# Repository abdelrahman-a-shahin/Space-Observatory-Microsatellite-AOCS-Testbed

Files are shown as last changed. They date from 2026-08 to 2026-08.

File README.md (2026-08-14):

# Space-Observatory-Microsatellite-AOCS-Testbed
My graduation project at Aerospace Engineering, New Mansoura University, in Egypt. Going through the design, simulation, and implementation process of a ground model customized cube-sat for space observation. And to validate the CubeSat's attitude, navigation & control an AOCS testbed was made to simulate Earth's geomagnetic field and the frictionless motion of the satellite in space.



https://github.com/user-attachments/assets/0b6dd6ed-a356-4bd0-b43c-fc6ba49cf2e2

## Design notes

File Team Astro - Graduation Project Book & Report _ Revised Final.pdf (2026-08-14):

New Mansoura University

Faculty of Engineering

Aeronautical & Aerospace Engineering Program

## Graduation Project

## Space Observatory Micro-Satellite & AOCS Testbed

## Students’ names:

Name | ID Number
Abdelrahman Ahmed Abdelhadi Shahin | 221101236
Abdelrahman Elsaied Nassim Yakoub | 221101237
Ezzeldeen Mohammed Amin AboElkasim | 221101241
Abdelrahman Ehab Awad Ramdan | 221101238
Dana Elsayed Abdelhadi Elansari | 221101234
Mostafa Hassan Anwar Abdallah | 221101257
Ali Abdelhakim Ibrahim Sakr | 221101242
Amr Khaled Youssef Balat | 221101245

## Supervised by:

Assoc. Prof. Sara Ahmed El-Bahloul | Assoc. Prof. Osama El-Shazly Habib

Dr. Ahmed Salah Saad

Spring 2026

## ACKNOWLEDGEMENTS

First and foremost, we would like to express our deepest gratitude and sincere

appreciation to Prof. Wael Seddik, Dean of the Faculty of Engineering, for his continuous

support, encouragement, and efforts in providing a motivating academic environment

that enables students to develop their engineering knowledge and practical skills.

We would also like to extend our sincere thanks to Assoc. Prof. Sara Elbahloul, Program

Directors, for her valuable guidance, continuous follow-up, and dedication to the

development of the program and its students.

Our heartfelt appreciation goes to our project supervisors, Assoc. Prof. Sara Ahmed El-

Bahloul, Assoc. Prof. Osama El-Shazly Habib, and Dr. Ahmed Salah Saad, for their

invaluable supervision, constructive feedback, technical guidance, and continuous

support throughout all stages of this graduation project. Their knowledge, experience,

and encouragement were essential to the successful completion of this work.

Special thanks are also extended to our project mentor, Eng. Ismail Ezz El-Din, for his

valuable technical advice, practical support, and continuous assistance during the design,

implementation, and testing phases of the project.

Finally, we would like to express our deepest gratitude to our families for their endless

love, patience, encouragement, and support throughout our academic journey. Their

belief in us has been a constant source of motivation and strength, and this achievement

would not have been possible without them.

## ABSTRACT

The Egyptian Gamma Observation Satellite (EGOS-1) is a space observatory micro-

satellite designed and developed by Team Astro at New Mansoura University as part of

the 2025–2026 graduation project for the Aeronautical and Aerospace Engineering

Program. The project encompasses two parallel and complementary deliverables: the

conceptual design and systems-level engineering of a gamma-ray observation micro-

satellite, and the design, fabrication, and experimental validation of a ground-based

Attitude and Orientation Control System (AOCS) evaluation testbed simulating the LEO

magnetic and rotational environment.

EGOS-1 is a 20 × 20 × 20 cm micro-satellite designed for a sun-synchronous circular orbit

at 550 km altitude. Its primary payload is a NaI(Tl) scintillation detector coupled to a

BPW34 photodiode array for gamma-ray flux detection. Structural integrity was

confirmed through static, thermal, and modal finite-element analyses, yielding a factor of

safety of 7 under 10G launch loading, thermal compliance at a peak frame temperature of

411.51 K, and adequate dynamic stiffness across six vibration modes. Attitude control is

achieved via a reaction wheel, dual custom magnetorquers, and a PSO-tuned PD controller

executed on an ESP32 microcontroller, with real-time telemetry accessible through a Wi-

Fi-hosted dashboard.

The AOCS testbed comprises a three-axis rectangular Helmholtz cage and a spherical

aerostatic air bearing. The Helmholtz cage generates a uniform magnetic field in the LEO

operational range (0.3–0.6 Gauss at 5 A), confirmed by Wolfram-based magnetic

simulation and real-world testing. The air bearing, 3D-printed in PLA with 13 × 1.0 mm

orifices at 6 bar supply pressure, was validated by independent SOLIDWORKS Flow Simulation and ANSYS Fluent 2025 R1 analyses, with both tools agreeing on a lifting force

of 49.85 N to within 0.01%. Both the satellite Earth prototype and the testbed were

successfully fabricated and demonstrated at New Mansoura University.

## TABLE OF CONTENTS

## LIST OF FIGURES

Figure 5 EGOS-1 ground track illustrating the satellite passing over Egypt for the downlink

Figure 6 Eclipse simulation for EGOS-1 in orbit using SatCatalog. The maximum eclipse

Figure 7 The payload sensor consisting of a NaI(Tl) crystal incapsulated in an aluminum case (transparent in the figure) and connected to the BPW34 light sensors at the bottom.

Figure 10 Exploded view of EGOS-1 illustrating all sub-systems and components in a nest

Figure 11 Mesh quality plot and boundary conditions showing the red arrow as the 10G external load and the green arrows as the fixture on the bottom plate in the left image.

Figure 12 Boundary conditions of the thermal simulation of EGOS-1 showing the arrows as

Figure 13 Mesh quality plot for the modal analysis (the left image), and the fixed support of

Figure 18 Results summary of the static, thermal and modal analysis of EGOS-1 microsatellite.

Figure 19 3D CAD model performed on SOLIDWORKS of the helmholtz cage structure &

Figure 20 Spherical air bearing 3D CAD model on SOLIDWWORKS, showing the isometric view and the sectional front view to illustrate the air chamber and the central orifice. .51

Figure 21 Full system 3D CAD model showing 2 various views, and the top view to illustrate the gripping mechanism on the microsatellite, showing 2 diagonal tight grips and 2 loose
grips | 51

Figure 22 The input parameters for the Helmholtz cage simulation to solve for the magnetic
flux density and the homogenious distance | 52

Figure 23 SOLIDWORKS Flow Simulation boundary conditions for the spherical air bearing: inlet total pressure 600,000 Pa (left) and environment pressure outlet 101,325 Pa (right).
Simulation goals are listed in the centre panel | 53

Figure 24 ANSYS Fluent 2025 R1 setup for the spherical air bearing CFD simulation: bowl geometry with pressure inlet at 600,000 Pa gauge (normal to boundary), and velocity
streamline initialisation showing the eight orifice inlet jets | 54

Figure 25 Wolfram Demonstration magnetic simulation for the XZ plane (2a = 0.75 m, N = 5, I = 5 A): B_z vs z (left) and B_z vs y (right) profiles, confirming B_z(0,0,0) = 0.542915
Gauss and a broad uniform-field plateau | 55

Figure 26 SolidWorks Flow Simulation results at iteration 85: velocity flow trajectories (left, scale 0–365 m/s) showing symmetric air film formation between the orifice jets and the sphere surface. The results table (right) shows GG Force Y = 49.845 N (averaged)......56

Figure 27 The final purchased components (right image) & The final schematic (left image).
| 61

Figure 28 Plate assembly of the frame using the tab-and-slot feature to install the mounting
strips that will hold the plates together, also showing the mounting shelf | 62

Figure 29 The CNC laser cutting process of the structural frame plates (left image), the plates and mounting strips before assembly (middle image), the plates during assembly using
4mm button head bolts with nuts (right image.) | 62
Figure 30 Telemetry dashboard for EGOS-1 microsatellite | 64
Figure 31 The control algorithim for the microsatellite's software | 65

Figure 32 The U-channel aluminum profile (left image), The 4mm2 stranded insulated wire
(middle image), The zip ties used as fasteners (right image) | 67

Figure 33 Final modelling of the assembly on SOLIDWORKS (left image), The 3D printing process of the parts (middle images), Final implemented assembly with stand (right
image) | 67
Figure 34 Testbed operation diagram | 69

Figure 35 Full testbed + specimen project operating in a lab at New Mansoura University.69

## LIST OF TABLES

Table 4 Helmholtz cage magnetic simulation results: central field and uniform region for each

Table 5 SolidWorks Flow Simulation results for the spherical air bearing (6 bar inlet, 13 × 1.0

Table 6 ANSYS Fluent 2025 R1 CFD results for the spherical air bearing. Both tools agree on

CHAPTER 1:INTRODUCTION

# 1. Introduction

Space science has emerged as one of the most transformative fields driving scientific

progress and technological development in the modern era. Over the past several

decades, humanity’s ability to deploy instruments and platforms beyond the confines of

the Earth’s atmosphere has fundamentally altered our understanding of the universe and

has enabled a wide spectrum of applications that directly underpin daily life on Earth.

From global telecommunications networks to precise navigation systems, from climate

monitoring to disaster response, space-based infrastructure has become an essential

element of the modern world’s operational backbone.

The development and launch of artificial satellites represent arguably the single most

consequential achievement of the space age. Since the launch of Sputnik 1 in 1957,

satellites have evolved from simple radio beacons into sophisticated engineering

platforms carrying instruments of extraordinary complexity and sensitivity. Today,

constellations of satellites provide continuous coverage of the Earth’s surface, enable

real-time global communications, deliver precise positioning data to billions of users, and

support scientific investigations ranging from Earth observation to deep-space

astrophysics. The cumulative economic, social, and scientific impact of satellite

technology is difficult to overstate BeiDou provide sub-meter positioning accuracy [14].

Artificial satellites serve a remarkable diversity of functions. In the domain of

telecommunications, geostationary satellites relay voice, data, and broadcast signals

across continents and oceans, forming the invisible backbone of the global internet and

telephone infrastructure. In navigation, constellations such as the Global Positioning

System (GPS), GLONASS, Galileo, and BeiDou provide sub-meter positioning accuracy

that supports aviation, maritime navigation, precision agriculture, autonomous vehicles,

and emergency services. In meteorology, polar-orbiting and geostationary weather

satellites continuously monitor atmospheric conditions, enabling forecasts that save lives

and protect economies. In Earth observation, multispectral and hyperspectral sensors

map land use, monitor deforestation, track sea-ice extent, and assess agricultural yields,

providing decision-makers with data critical for environmental stewardship and

sustainable development [17].

CHAPTER 1:INTRODUCTION

Beyond these utilitarian applications, satellites have opened an entirely new window on

the universe. Space-based observatories, freed from the blurring and absorptive effects

of the Earth’s atmosphere, observe the cosmos across the full electromagnetic spectrum,

from gamma rays and X-rays through ultraviolet, visible, and infrared wavelengths to

radio frequencies. Missions such as the Hubble Space Telescope, the Chandra X-ray

Observatory, the Fermi Gamma-ray Space Telescope, and the James Webb Space

Telescope have revolutionized astrophysics, cosmology, and planetary science, delivering

data that challenge and refine our theoretical understanding of the universe’s origin,

structure, and evolution [20].

In recent years, the satellite industry has undergone a profound democratization driven

by the rise of micro-satellites and CubeSats. Traditional large satellites, with masses

measured in hundreds or thousands of kilograms and development costs in the hundreds

of millions of dollars, have historically been accessible only to major space agencies and

large commercial entities. Micro-satellites, defined as spacecraft with a mass between

approximately 10 and 100 kilograms, and even smaller CubeSats based on standardized

10 × 10 × 10 cm unit (1U) form factors, have dramatically lowered the barriers to space

access. Standardized launch vehicle interfaces, off-the-shelf electronic components, and

streamlined development methodologies have enabled universities, research

institutions, and technology start-ups to design, build, and launch space-qualified

platforms on timescales of one to three years and at costs orders of magnitude lower than

traditional satellite programs [15].

This democratization has had a catalytic effect on both scientific research and

engineering education. Universities around the world now routinely develop and operate

small satellites as educational platforms, training the next generation of aerospace

engineers in systems integration, orbital mechanics, attitude control, communications,

and mission operations. At the same time, micro-satellites are increasingly used for

genuine scientific investigations, commercial Earth observation, technology

demonstration, and in-orbit validation of new components and systems. The

miniaturization of sensors, processors, and power systems has reached a point where a

spacecraft the size of a shoebox can carry scientifically meaningful payloads and generate

commercially valuable data.

CHAPTER 1:INTRODUCTION

Within the constellation of satellite subsystems, the Attitude and Orientation Control

System (AOCS), sometimes referred to as the Attitude Determination and Control System

(ADCS), occupies a position of particular criticality. The AOCS is responsible for sensing

the satellite’s current orientation in space, computing the required corrective maneuvers,

and commanding actuators to reorient the spacecraft so that its instruments, antennas,

and solar panels are pointed toward their intended targets with the required accuracy.

For a space observatory, this pointing requirement is especially demanding: scientific

instruments must be held precisely on a celestial target long enough to collect statistically

meaningful data, and the pointing knowledge must be accurate enough to assign the

collected data to the correct position on the sky.

A typical AOCS integrates several types of sensors to determine attitude. Magnetometers

measure the local geomagnetic field vector, which can be compared to a model of the

Earth’s field to infer orientation. Gyroscopes, either mechanical or micro-

electromechanical (MEMS), measure angular rates and provide high-bandwidth attitude

rate information. Sun sensors detect the direction of the Sun relative to the spacecraft

body frame. Star trackers, the most accurate of all attitude sensors, identify patterns of

stars in their field of view and compare them to an onboard star catalog to determine

inertial pointing with arc-second precision. On the actuator side, reaction wheels provide

fine torque control about all three axes by exchanging angular momentum between the

wheel and the spacecraft. Magnetorquers generate magnetic dipole moments that

interact with the Earth’s field to produce control torques, and are particularly useful for

detumbling after launch and for desaturating reaction wheels [18].

The complexity of the AOCS, and the consequences of its failure for mission success, make

thorough ground testing essential before a satellite is committed to orbit. Once in space,

the satellite cannot be physically accessed for repair, and the cost of a failed mission is

not merely the financial investment but the scientific opportunity that is irretrievably

lost. Ground-based AOCS testbeds allow engineers to exercise sensors, actuators, and

control algorithms in a controlled laboratory environment that simulates the key

characteristics of the space environment: a frictionless rotational interface that mimics

microgravity, and a controlled magnetic field environment that replicates the

geomagnetic conditions the satellite will experience in orbit.

CHAPTER 1:INTRODUCTION

Egypt stands at a pivotal juncture in its development of national space capabilities. The

Egyptian Space Agency (EgSA), established in 2018, has articulated a national space

strategy that includes the development of indigenous satellite design and manufacturing

capabilities. In this context, academic programs in aerospace engineering at Egyptian

universities play a vital role in building the human capital that will realize these national

aspirations. Projects that challenge students to design, analyze, and fabricate real space-

qualified hardware contribute directly to the development of a domestic engineering

talent pool capable of supporting Egypt’s long-term space ambitions.

The Space Observatory Micro-Satellite and AOCS Evaluation Testbed project, designated

EGOS-1, is designed in precisely this spirit. The project pursues two complementary

objectives. The first is the conceptual design and analysis of a micro-satellite platform

optimized for gamma-ray observation from Low Earth Orbit, with a scientific mission

focused on the detection and characterization of gamma-ray flux from deep-space

sources. The second is the design, analysis, and fabrication of a laboratory-based AOCS

testbed capable of simulating the magnetic and rotational environment of LEO, enabling

the rigorous validation of AOCS sensors, actuators, and control algorithms prior to any

future launch campaign [21].

Gamma-ray astronomy represents one of the most scientifically rich and technically

challenging domains of space-based observation. Gamma rays are the highest-energy

photons in the electromagnetic spectrum, with energies typically exceeding 100 keV and

often reaching into the GeV and TeV ranges. They are produced by the most energetic

processes in the universe: the accretion of matter onto black holes and neutron stars, the

annihilation of matter and antimatter, cosmic-ray interactions with interstellar medium,

and the violent explosions of massive stars known as gamma-ray bursts. Because gamma

rays are entirely absorbed by the Earth’s atmosphere, they can only be detected by

instruments deployed above the atmosphere, making space-based observatories an

absolute requirement for gamma-ray astronomy.

The EGOS-1 payload employs a sodium iodide thallium-doped scintillation detector, a

technology with a long and proven heritage in space-based gamma-ray detection. When

a gamma-ray photon interacts with the NaI(Tl) crystal, it deposits its energy through a

cascade of photoelectric, Compton scattering, and pair-production interactions,

CHAPTER 1:INTRODUCTION

ultimately producing a burst of visible-wavelength scintillation light. This light is

detected by an array of BPW34 high-sensitivity photodiodes mounted on the crystal’s

lower surface, whose output is amplified and digitized for onboard storage and

subsequent downlink to the ground station.

The project’s dual-component structure—satellite design and AOCS testbed development

conducted in parallel and validated against a common set of mission requirements—

reflects a systems engineering philosophy that is well established in the professional

aerospace community. By developing the testbed in close coordination with the satellite

design, the team ensures that the testbed’s simulation capabilities are directly matched

to the operational envelope of the AOCS that will fly on EGOS-1. Conversely, the testbed

provides a concrete engineering product of immediate value for academic research,

independent of whether and when the satellite itself is eventually launched.

The remainder of this report is organized as follows. Section 2 defines the problem

statement that motivates the project. Section 3 states the project objectives. Section 4

reviews the relevant literature on microsatellite design, gamma-ray payload technology,

and AOCS testbed approaches. Section 5 describes the engineering methodology adopted.

Section 6 presents the technical approach, including design parameters, CAD models,

simulation setups, and results for both the microsatellite and the AOCS testbed. Section 7

describes the deliverables and implementation plan. Section 8 identifies potential

stakeholders. Sections 9 and 10 provide the project conclusion and future work,

respectively.

### 1.1 Space Observatory Microsatellite

A space observatory micro-satellite is a compact, mass-constrained spacecraft

specifically designed to observe and study astronomical objects and physical phenomena

from a vantage point above the Earth’s atmosphere. The absence of atmospheric

absorption and distortion that afflicts ground-based observatories makes space-based

platforms uniquely capable of detecting radiation across the full electromagnetic

spectrum, including the gamma-ray, X-ray, and ultraviolet bands that are completely or

partially blocked by the atmosphere at sea level.

CHAPTER 1:INTRODUCTION

Micro-satellites in this category typically have masses in the range of 10 to 100 kilograms,

and their dimensions are constrained to fit within standardized launch vehicle

dispensers. Despite these mass and volume constraints, modern micro-satellites can

accommodate sophisticated scientific instruments, thanks to the continued

miniaturization of electronics, detectors, and mechanical structures. Advanced system-

on-chip processors provide the computational power needed for onboard data

processing and compression. Low-power, high-sensitivity detectors enable meaningful

science within tight power budgets. Compact attitude control actuators, including

reaction wheels the size of a hockey puck, provide the pointing stability needed for

scientific observation.

The EGOS-1 micro-satellite is designed to detect gamma-ray flux from astrophysical

sources, contributing to the growing body of data from space-based gamma-ray

observatories. Its orbit, subsystem architecture, structural design, and payload

configuration are described in detail in Section 6 of this report. The satellite is designed

with a mission lifetime of one to three years, depending on orbital decay and subsystem

reliability, and is intended to serve as a demonstration platform for Egyptian space

engineering capabilities as well as a scientific instrument contributing to international

gamma-ray observation programs.

### 1.2 AOCS Testbed

The Attitude and Orientation Control System Testbed is a ground-based experimental

platform engineered to simulate and evaluate the performance of a satellite’s attitude

control system in a controlled laboratory environment before the satellite is committed

to space. In the context of the EGOS-1 mission, the AOCS must maintain precise pointing

of the gamma-ray detector toward its intended observation targets, and it must do so

reliably throughout the satellite’s operational lifetime in the presence of environmental

disturbances including aerodynamic drag, solar radiation pressure, gravity gradient

torques, and geomagnetic perturbations.

The testbed enables the experimental validation of attitude sensors, actuators, and

control algorithms by replicating two key aspects of the space environment. The

Helmholtz cage, a system of three mutually orthogonal square coil pairs, generates a

uniform and programmable magnetic field within the cage’s central volume that

CHAPTER 1:INTRODUCTION

replicates the Earth’s geomagnetic field as experienced by a satellite in LEO. This allows

magnetometers and magnetorquers to be tested and calibrated under realistic field

conditions. The spherical air bearing provides a near-frictionless rotational interface on

which a satellite mock-up can rotate freely about all three axes, simulating the near-zero-

friction rotational environment of orbital free-fall.

Together, these two testbed components create a laboratory environment in which the

full AOCS control loop—sensor measurement, state estimation, control law computation,

and actuator command—can be exercised and validated before the satellite encounters

the real space environment. The ability to detect and correct design errors at this stage,

rather than after launch, is enormously cost-effective and is standard practice in

professional satellite engineering programs worldwide.

CHAPTER 2: PROBLEM STATEMENT

# 2. Problem Statement

The exploration of space and the systematic observation of astronomical phenomena

demand satellite systems of high precision, reliability, and operational robustness.

Traditional large satellites, while capable of delivering exceptional scientific data, involve

development costs measured in hundreds of millions of dollars and launch costs that are

beyond the reach of universities and most national space agencies, particularly in the

developing world. These financial barriers severely limit participation in space science

and the development of indigenous satellite engineering expertise.

Micro-satellites represent a compelling cost-effective alternative that has the potential to

democratize access to space-based observation. However, despite their lower cost, the

technical challenges associated with micro-satellite development are not proportionally

reduced. The accuracy and stability of satellite attitude control remain critical for mission

success regardless of satellite scale, and the engineering difficulty of achieving precise,

robust attitude control in a compact, power-constrained platform is substantial. Any

systematic error or instability in the AOCS will result in degraded pointing accuracy,

compromised data quality, and potentially mission failure.

In-orbit testing and debugging of AOCS failures is, in practice, extremely limited. Once a

satellite is deployed, direct physical access is impossible, and the only means of

diagnosing and correcting AOCS anomalies are telemetry analysis and software patch

upload over the communication link. This underscores the critical importance of

comprehensive ground testing before launch. However, the facilities needed for AOCS

ground testing—Helmholtz cages, air bearing platforms, vibration tables, thermal-

vacuum chambers—are expensive to procure and operate, and are typically found only

at major space agencies and large aerospace companies.

This project addresses a specific gap: the absence, within Egyptian academic institutions,

of a dedicated ground-based AOCS evaluation testbed that allows researchers and

engineering students to design, test, and validate satellite attitude control systems under

realistic simulated space conditions. By designing and fabricating such a testbed locally,

using a combination of commercial off-the-shelf components and custom-designed

mechanical parts, the project demonstrates that it is possible to create a functional,

CHAPTER 2: PROBLEM STATEMENT

scientifically meaningful AOCS test facility at a cost accessible to university programs.

Simultaneously, by designing the EGOS-1 microsatellite as the reference system for the

testbed, the project produces a complete systems engineering case study that links

mission requirements to testbed specifications.

CHAPTER 3: OBJECTIVES

# 3.Objectives

The main objectives of this project are:

To localize the fabrication of a high-efficiency, cost-effective Attitude and

Orientation Control System (AOCS) testing apparatus, enabling reliable experimental

validation of spacecraft attitude control subsystems. This involves the end-to-end design,

manufacturing, and assembly of the testing platform using locally sourced components

and domestic engineering expertise, thereby reducing dependence on imported systems.

The apparatus will be capable of simulating realistic rotational dynamics and disturbance

torques, providing a controlled environment in which AOCS algorithms and hardware

configurations can be rigorously evaluated, calibrated, and refined prior to integration

into the flight model.

To design a compact space observatory micro-satellite platform incorporating

advanced sensors and payloads, with AI-enhanced data acquisition and interpretation

for improved astronomical observation. The satellite platform will be engineered to meet

the stringent mass, volume, and power constraints characteristic of the micro-satellite

class, while accommodating a scientifically capable optical and sensing payload suite. The

integration of artificial intelligence and machine learning techniques into the onboard

data pipeline will enable autonomous feature extraction, anomaly detection, and

prioritized downlink of high-value observational data, significantly enhancing the

platform's scientific return within its operational constraints.

To provide affordable and accessible testing capabilities for universities and

research institutions, supporting hands-on experimentation and academic training in

satellite systems engineering. A central consideration in the design philosophy of the

testing apparatus is its replicability and ease of use within academic settings that may

have limited infrastructure or funding. By documenting the development process

thoroughly and optimizing the system for low-cost production, this project aims to

democratize access to spacecraft subsystem testing, enabling the next generation of

aerospace engineers to gain practical, laboratory-grade experience with real-world

satellite technologies.

CHAPTER 3: OBJECTIVES

To contribute to Egypt's advancement in space science and technology by designing

and prototyping the nation's first space observatory micro-satellite, fostering local

expertise and capability in aerospace engineering and scientific research. Beyond the

immediate technical deliverables, this project is positioned as a foundational milestone

in building a sustainable domestic space industry. Through the involvement of local

engineers, academic institutions, and research bodies, the project seeks to cultivate a

multidisciplinary knowledge base, stimulate innovation, and establish the technical

heritage necessary for Egypt to undertake increasingly ambitious space missions in the

future.

CHAPTER 4: LITERATURE REVIEW

# 4. Literature Review

This chapter provides a comprehensive review of prior research and technological

developments relevant to microsatellites, space observatory systems, and attitude

determination and control systems (AOCS). A thorough examination of the existing

literature is essential for understanding the current state of satellite technology,

identifying proven design methods and approaches, and recognizing the limitations and

challenges encountered in previous work. This review establishes a solid intellectual

foundation for the proposed project and informs the design decisions made in the

technical approach described in Chapter 6..

### 4.1 Space Observatory Microsatellite

### 4.1.1 Mission

Detection of gamma rays is one of the most effective methods for space observation, as

these high-energy particles originate from deep space and carry valuable information

about their sources . By analyzing the gamma-ray flux from specific regions, researchers

can gain insights into the physical characteristics of these areas, enhancing our

understanding of the universe. In line with this, the primary mission of the microsatellite

will focus on gamma-ray detection [1]. To clearly reflect its purpose, the microsatellite

has been named The Egyptian Gamma Observation Satellite (EGOS-1).

### 4.1.2 Orbit Design

The selection of an appropriate orbit plays a critical role in the performance of gamma-

ray instruments. Research indicates that near-equatorial, low-altitude circular orbits,

typically ranging from 500 to 600 km, offer optimal conditions by minimizing background

radiation [2]. In such Low Earth Orbits (LEO), the Earth's magnetic field provides effective

shielding against cosmic rays and solar energetic particles, enhancing the accuracy and

sensitivity of measurements. For the proposed space observatory microsatellite, this

orbital regime achieves a favorable balance between scientific capability, radiation

protection, operational stability, and cost efficiency, making it a practical and suitable

choice for a small satellite platform.

CHAPTER 4: LITERATURE REVIEW

### 4.1.3 Payload

Gamma-ray detector designs for small satellite missions typically employ arrays of

scintillating crystals coupled with photosensors to achieve the combination of high

detection efficiency, good energy resolution, and compact form factor required for space

deployment. Arneodo et al. [3] present a reference detector architecture featuring a core

of four scintillating crystal elements, each individually read out by a dedicated

photosensor, housed within a compact aluminum enclosure that provides mechanical

support and electromagnetic shielding. This architecture is adopted as the basis for the

EGOS-1 payload design, with specific adaptations to accommodate the volume and mass

constraints of the 20 × 20 × 20 cm satellite structure.

The EGOS-1 payload uses a sodium iodide thallium-doped (NaI(Tl)) scintillation crystal

as its primary sensing element. NaI(Tl) is a well-characterized scintillator with a long

heritage in space-based and laboratory gamma-ray detection, offering a favorable

combination of high detection efficiency, adequate energy resolution, relatively low cost,

and commercial availability in radiation-hardened grades. The scintillation light

produced by gamma-ray interactions in the crystal is detected by BPW34 high-sensitivity

photodiodes, whose output is amplified and digitized for onboard storage and downlink.

### 4.1.4 Sub-systems

A microsatellite, such as EGOS-1, consists of several key subsystems that work together

to ensure mission success in Low Earth Orbit (LEO) [4]:

- Onboard Computer (OBC): Manages data from sensors and payload, executes

ground commands, and coordinates all satellite operations.

- Attitude and Orbit Control System (AOCS): Maintains the satellite’s orientation

using sensors (magnetometers, gyroscopes, sun sensors) and actuators (reaction

wheels, magnetorquers), enabling accurate pointing of instruments.

- Communication (COMMS): Handles data exchange between the satellite and

ground stations, including telemetry, tracking, and command (TT&C).

- Power Subsystem (EPS): Supplies energy through solar panels and batteries,

ensuring continuous operation and protecting sensitive electronics.

CHAPTER 4: LITERATURE REVIEW

These subsystems are integrated to achieve reliable satellite performance and successful

mission operations in LEO.

### 4.1.5 Frame & Housing

The structural frame of EGOS-1 serves as the primary mechanical load-bearing element

of the satellite, providing mounting interfaces for all subsystems, defining the external

envelope of the spacecraft, and protecting internal components from the mechanical

loads experienced during launch [4]. The frame is designed as a compact cubic structure

with external dimensions of 20 × 20 × 20 cm, fabricated from Aluminum Alloy 6061-T6

sheet of 1.5 mm thickness [4]. This alloy is widely used in satellite structural applications

due to its high strength-to-weight ratio, excellent machinability, good corrosion

resistance, and well-characterized behavior under the thermal cycling and radiation

environments of LEO [4] .

The frame incorporates a 10 cm diameter circular access hatch on the top panel to

facilitate assembly and integration of internal components, and dedicated mounting

interfaces for two deployable solar panels of 16.5 × 10 cm each. The internal architecture

follows a nested-stack configuration, in which subsystem boards are arranged in a

layered vertical stack and fastened by mechanical standoffs, maximizing the use of

available internal volume and simplifying the integration and testing procedure.

### 4.2 AOCS Testbed

### 4.2.1 Helmholtz Cage

Testing and calibrating the attitude determination and control sensors and actuators of a

satellite before flight requires the ability to generate a controlled and uniform magnetic

field in the laboratory that accurately replicates the Earth’s geomagnetic field at the

satellite’s operational orbit. The Earth’s magnetic field can be modeled as a magnetic

dipole with a surface field strength of approximately 30,000 nT at the equator, decreasing

with the cube of the geocentric distance and varying with magnetic latitude. For LEO

microsatellites at altitudes of 400 to 600 km, the field strength at the satellite’s location

is typically in the range of 20,000 to 60,000 nT (0.2 to 0.6 Gauss), depending on orbital

inclination and magnetic latitude.

CHAPTER 4: LITERATURE REVIEW

For microsatellites in Low Earth Orbit (LEO), typical values can be obtained from the

following equation [4] :

- Earth radius R = 6371 km
- Orbital altitude H = 400 − 600 km
- Magnetic latitude ϕ = 0° − 90°

The Helmholtz cage is the standard laboratory instrument used to generate this kind of

controlled uniform magnetic field [5]. A classical Helmholtz cage consists of two identical

circular coils, placed coaxially and separated by a distance equal to their radius. When

equal currents flow through both coils in the same direction, the first-order spatial

gradient of the magnetic field between the coil’s cancels, producing a region of high field

uniformity between and around the coils. A three-axis Helmholtz cage, consisting of three

mutually orthogonal pairs of coils, can generate an arbitrary uniform magnetic field

vector within its central working volume [5].

For the EGOS-1 AOCS testbed, square coil pairs are used instead of circular ones, because

square coils produce a larger region of high field uniformity for a given coil aperture [5].

The field uniformity is optimized when the ratio of coil separation to coil side length is γ

= 0.5445 [5], the value that eliminates the second-order spatial gradient term at the cage

center. The three coil pairs are oriented in the XZ, XY, and YZ planes to enable

independent control of the magnetic field vector in all three spatial directions.

A Helmholtz cage, made of three orthogonal coil pairs, can create uniform magnetic fields

in its central volume. By adjusting the currents, it can replicate the Earth’s field at

different altitudes and latitudes, allowing calibration of magnetometers, testing of

magnetic actuators, and validation of AOCS algorithms before LEO deployment [5].

CHAPTER 4: LITERATURE REVIEW

### 4.2.2 Spherical Air Bearing

The spherical air bearing is the second principal component of the AOCS testbed. Its

function is to provide a mechanical interface on which a satellite mock-up can rotate

freely about all three axes with minimal friction, simulating the near-frictionless

rotational freedom that a satellite experiences in the microgravity environment of orbit.

Without such a frictionless support, ground-based tests of AOCS algorithms would be

dominated by friction torques from the bearing that are many orders of magnitude larger

than the disturbance torques the AOCS must reject in orbit, making the test results

misleading and non-representative [6].

The spherical air bearing operates on the aerostatic principle: compressed air is fed

through a network of orifices distributed over the inner surface of a hemispherical bowl,

forming a thin film of pressurized air between the bowl and a spherical ball on which the

satellite mock-up is mounted. This air film supports the weight of the satellite mock-up

and eliminates solid-to-solid contact, reducing the friction coefficient at the bearing interface to values in the range of 10⁻⁴ to 10⁻⁵, comparable to the disturbance torque

environment in LEO. The design of the air bearing, including the selection of orifice

diameter, number, and distribution, the plenum volume, and the supply pressure, must

be carefully optimized to achieve both adequate lifting force and a sufficiently uniform

air film pressure distribution [6].

CHAPTER 5: METHODOLOGY

# 5. Methodology

This project adopts a comprehensive and structured engineering methodology for the

design, development, and validation of the Egyptian Gamma Observation Satellite

(EGOS-1), along with its Attitude Determination and Control System (AOCS) testbed. The

methodology combines theoretical analysis, system-level design, and experimental

validation to ensure that the proposed system achieves its mission objectives with high

reliability and accuracy.

The methodology is centered around two main components: the microsatellite system

and the AOCS testbed. These components are developed in parallel and are closely

interconnected throughout the project lifecycle.

The first component focuses on the design and development of the microsatellite. This

begins with defining the mission objective, which is the detection of gamma rays in Low

Earth Orbit (LEO). Based on this objective, a set of system requirements is established,

including constraints related to power consumption, communication capabilities, and

attitude control accuracy. The microsatellite is then structured into its primary

subsystems: the Onboard Computer (OBC), which manages data processing and system

operations; the AOCS, which controls the satellite’s orientation; the Communication

subsystem, which enables data transmission with ground stations; and the Power

subsystem, which ensures continuous energy supply. Each subsystem is carefully

designed and analyzed to ensure compatibility and efficient integration within the overall

system.

The second component of the methodology involves the development of the AOCS

testbed. Since the AOCS plays a critical role in maintaining the correct orientation of the

satellite, it must be thoroughly validated before deployment. For this purpose, a

laboratory-based testbed is designed to simulate the space environment. A key element

of this setup is the Helmholtz cage, which is used to generate a controlled and uniform

magnetic field that replicates the Earth’s geomagnetic field. This allows accurate testing

and calibration of AOCS sensors, such as magnetometers, and actuators, such as

CHAPTER 5: METHODOLOGY

magnetorquers. The testbed provides a controlled environment where the performance

of attitude control algorithms can be evaluated under repeatable conditions.

In parallel with both components, mathematical modeling and simulation are conducted.

These simulations are used to analyze the behavior of the microsatellite and its AOCS

under different operational scenarios, including variations in orbital conditions and

external disturbances. The simulation results are then compared with experimental data

obtained from the AOCS testbed to ensure consistency and validate system performance.

Finally, the microsatellite subsystems and the AOCS testbed are integrated and tested as

a complete system. This stage ensures that all components function together as intended

and that the system meets the predefined mission requirements. This combined

approach of design, simulation, and experimental validation significantly reduces risks

and enhances the reliability of the proposed system.

### 5.1 Design Framework

The design framework represents the practical implementation of the methodology and

provides a clear and organized structure for the project workflow. It is based on a top-

down approach and is divided into two main parallel tracks: the microsatellite

development track and the AOCS testbed development track. These tracks are

interconnected and converge during the integration and validation phase. Shown in

Figure 1 is the design steps for both systems:

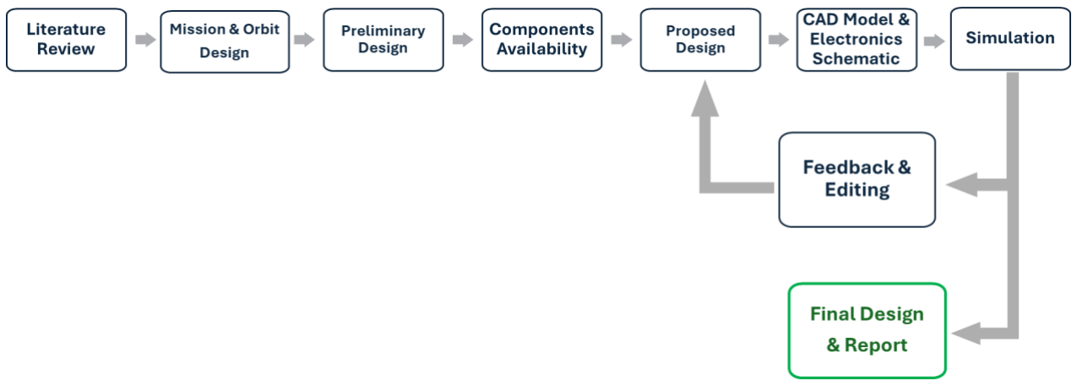
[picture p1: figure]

Figure 1 Workflow diagram for the technical design of the project.

CHAPTER 5: METHODOLOGY

### 5.1.1 Microsatellite Development Track

This track focuses on the complete design and development of the EGOS-1 microsatellite.

It begins with mission definition and requirement analysis, where the objectives of

gamma-ray detection are translated into technical specifications. The system

architecture is then developed by dividing the satellite into its main subsystems (OBC,

AOCS, Communication, and Power). Each subsystem is designed and analyzed

individually, followed by system-level integration. Modeling and simulation are also

performed within this track to evaluate system performance and ensure that the design

meets mission requirements.

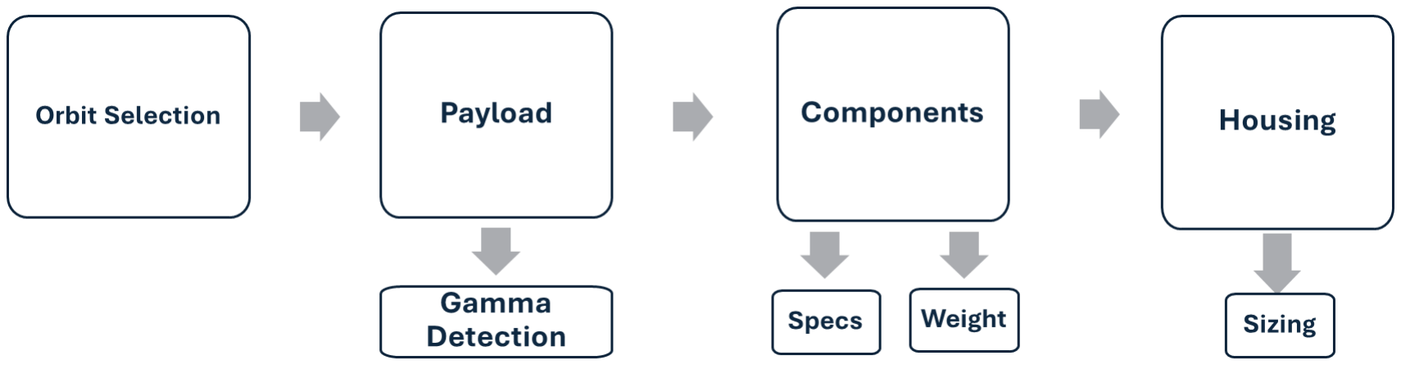
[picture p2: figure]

Figure 2 Workflow diagram for the design process of EGOS-1.

### 5.1.2 AOCS Testbed Development Track

This track is dedicated to the experimental validation of the attitude control system. It

involves designing and implementing the AOCS testbed, including the Helmholtz cage for

magnetic field simulation. The testbed is used to calibrate sensors, test actuators, and

validate control algorithms. This experimental approach ensures that the AOCS performs

accurately in a controlled environment before being applied to the actual microsatellite

system.

CHAPTER 5: METHODOLOGY

### 5.1.3 Integration and Validation

In this final stage, both tracks are combined. The results obtained from simulations and

experimental testing are compared and analyzed to evaluate overall system performance.

Any discrepancies are addressed through design refinement and optimization. This stage

ensures that the microsatellite and its AOCS meet all mission requirements and are ready

for deployment in Low Earth Orbit.

### 5.2 Gantt Chart

The project is planned across two academic semesters. The first semester covers the

design, modelling, and simulation phase, while the second semester focuses on

implementation and hardware fabrication.

Figure 3 presents the Gantt chart for the first semester activities, covering the design,

modelling, and simulation phase of the project, with tasks distributed across all team

members. While Figure 4 presents the Gantt chart for the second semester, covering the

implementation phase including hardware procurement, fabrication, assembly, and

testing activities.

CHAPTER 5: METHODOLOGY

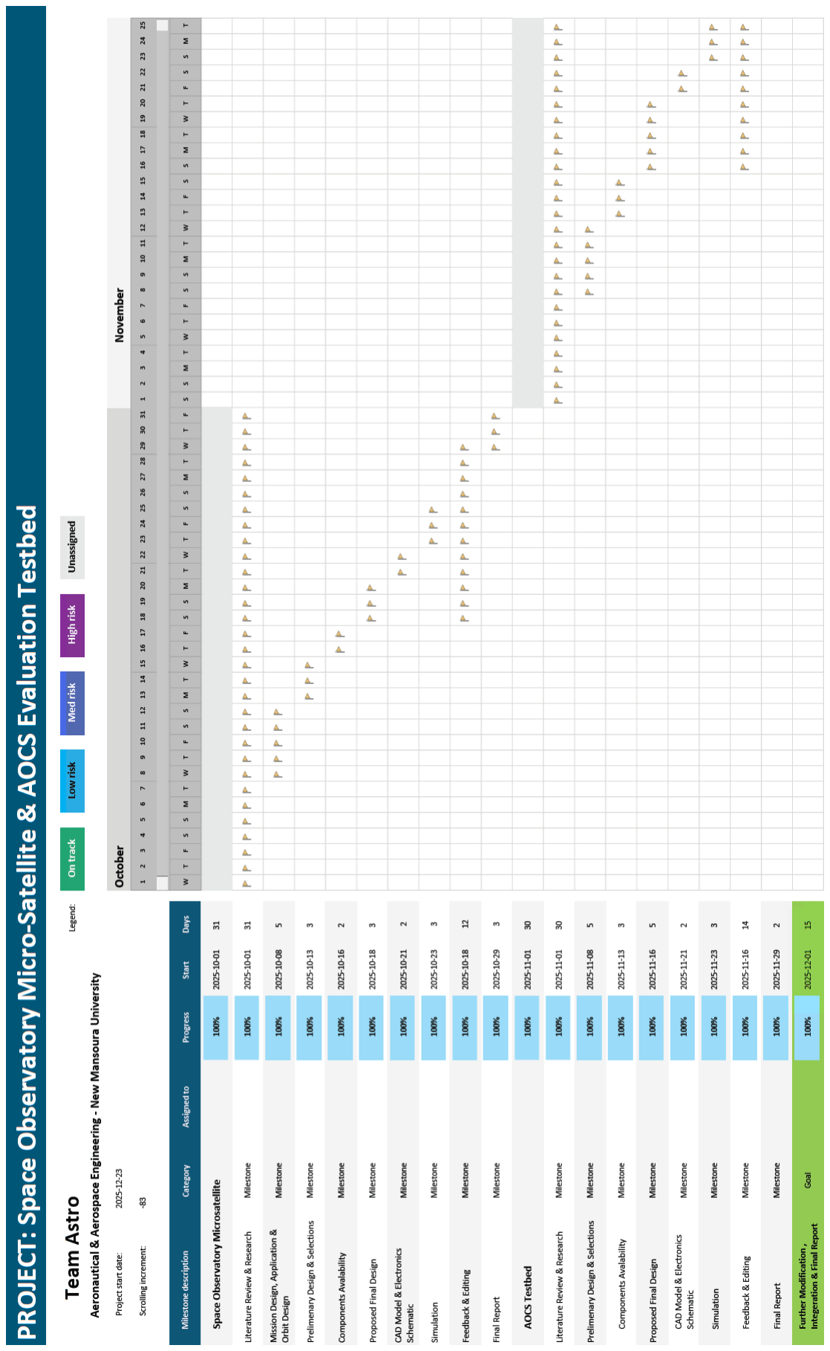
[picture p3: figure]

Figure 3 First semester Gantt Chart (Designing, Modelling & Simulation Phase)

CHAPTER 5: METHODOLOGY

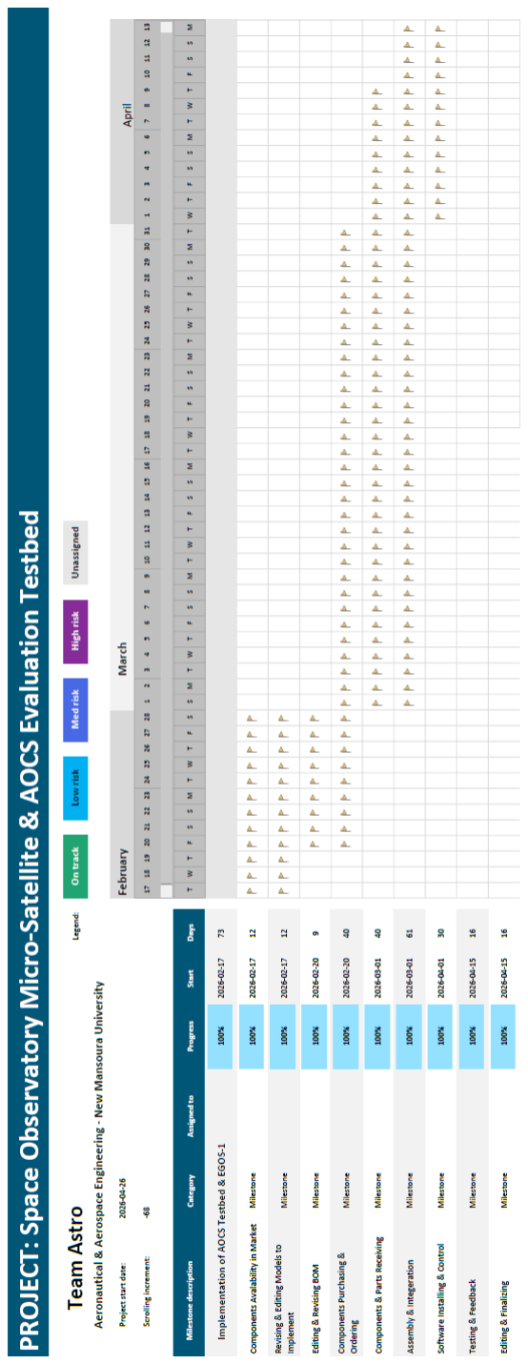
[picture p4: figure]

Figure 4 Second semester Gantt Chart (Implementation Phase)

CHAPTER 6: TECHNICAL APPROACH

# 6. Technical Approach

This chapter presents the technical methodology adopted for the design, modelling, and

simulation of The Space Observatory Microsatellite and The Attitude And

Orientation Control Subsystem (AOCS) Testbed. The approach follows a systems

engineering methodology, integrating structural design, subsystem configuration,

attitude dynamics modelling, and numerical simulation. The main objective is to ensure

that the proposed microsatellite meets the mission requirements, particularly in terms of

stability, pointing accuracy, and operational feasibility for space observation

applications. In addition to the complete successful operation of the AOCS testbed.

### 6.1 Space Observatory Microsatellite

### 6.1.1 Design Parameters

The design parameters define the fundamental characteristics and operational

constraints of the microsatellite. These parameters are carefully selected to achieve

optimal system performance while ensuring feasibility within the limitations of

microsatellite platforms.

The satellite mass and dimensions are minimized to comply with launch requirements

and to improve overall system efficiency. The power subsystem is designed based on

solar energy generation and onboard battery storage, ensuring sufficient energy

availability for continuous subsystem operation.

The payload is designed to achieve high sensitivity and accuracy within constrained

resources, making it suitable for space observation missions. Communication bandwidth

is optimized to enable efficient data transmission between the satellite and ground

stations.

Additional parameters include thermal operating limits, structural integrity, and mission

lifetime, which is typically expected to range from one to three years depending on

environmental conditions and system reliability.

CHAPTER 6: TECHNICAL APPROACH

### 6.1.2 Design Environment

The Space Observatory Microsatellite is designed to operate in the Low Earth Orbit (LEO)

environment, which is characterized by harsh and highly variable space conditions. These

include vacuum, radiation exposure, microgravity, and significant thermal cycling due to

alternating periods of sunlight and eclipse. Such environmental factors have a direct

influence on the design of the satellite subsystems, particularly the scientific payload.

Within this environment, the payload is specifically designed for gamma-ray detection

using a sodium iodide thallium-doped (NaI(Tl)) scintillation crystal. The crystal functions

as the primary sensing element, where incident gamma radiation interacts with the

material and is converted into visible light through the scintillation process.

To operate effectively under space conditions, the NaI(Tl) crystal is enclosed within an

aluminum casing, providing mechanical protection and environmental shielding. The

optical signals generated by the crystal are detected using multiple BPW34 high-

sensitivity photodiodes mounted on the lower surface of the crystal. These photodiodes

act as transducers, converting light signals into electrical signals for further processing.

The resulting electrical output is then passed through an amplification stage to enhance

signal strength and improve measurement readability prior to data acquisition and

storage within the onboard system. This signal conditioning process is essential to ensure

accurate data interpretation under the noisy and high-radiation conditions of the space

environment.

Overall, the design of the payload is closely driven by the constraints of the LEO

environment, where radiation tolerance, thermal stability, and structural robustness are

critical factors affecting system performance and reliability.

CHAPTER 6: TECHNICAL APPROACH

The following Table 1 illustrates the orbit parameters values for EGOS-1:

Table 1 EGOS-1 orbit parameters

Parameter | Symbol | Value | Unit
Orbital Altitude | h | 550 | km
Eccentricity | e | 0 | -
Inclination | i | 98.1 | degrees

Right Ascension of
Ascending Node | Ω | 70 | degrees
Orbital Period | T orbit | 95.7 | minutes
Orbital Velocity | S orbit | 7.6 | km/s

The orbital parameters mentioned in Table 1 define the characteristics and motion of the

satellite in its orbit around Earth. The orbital altitude (h) represents the height of the

satellite above the Earth's surface, which in this case is 550 km. The eccentricity (e)

describes the shape of the orbit; a value of zero indicates a perfectly circular orbit. The

inclination (i) is the angle between the satellite’s orbital plane and the Earth's equatorial

plane, determining the ground coverage of the satellite and here measured as 98.1°. The

right ascension of the ascending node (Ω) defines the orientation of the orbit in space and

represents the angle in the equatorial plane from the reference direction (vernal equinox)

to the ascending node, where the satellite crosses the equator moving northward, with a

value of 70°. The orbital period (T orbit) is the time required for the satellite to complete

one full revolution around the Earth, which is approximately 95.7 minutes. Finally, the

orbital velocity (S orbit) represents the speed of the satellite as it travels along its orbit,

which is approximately 7.6 km/s for this configuration [4].

Using the SatCatalog design tool, the satellite’s ground track was generated to analyze its

orbital path illustrated in Figure 5. Additionally, the eclipse duration was calculated

illustrated in Figure 6, representing the period during which the satellite operates

without solar power and relies entirely on its batteries.

This parameter is critical, as it directly impacts battery sizing and ensures reliable

operation during periods of solar unavailability.

CHAPTER 6: TECHNICAL APPROACH

Figure 5 EGOS-1 ground track illustrating the satellite passing over Egypt for the downlink process.

Figure 6 Eclipse simulation for EGOS-1 in orbit using SatCatalog. The maximum eclipse duration is around 40 minutes.

### 6.1.3 Payload Design

The payload design consists of a compact, robust radiation sensing module centered

around a thallium-activated sodium iodide (NaI(Tl)) scintillation crystal, selected for its

CHAPTER 6: TECHNICAL APPROACH

high light yield and proven efficiency in gamma-ray detection. The crystal is securely

encapsulated within a cylindrical aluminum housing, which provides mechanical

protection, electromagnetic shielding, and effective thermal stability while maintaining a

lightweight profile suitable for UAV integration. The lower section of the assembly

incorporates an array of BPW34 photodiodes, strategically arranged to maximize photon

collection from scintillation events and ensure uniform sensitivity across the crystal

volume. This configuration enables efficient conversion of incident radiation into

measurable electrical signals with minimal loss. The modular structure, as illustrated in

Figure 7 through the 3D, front, and bottom views, facilitates ease of assembly,

maintenance, and potential scalability, while ensuring reliable operation under varying

environmental and flight conditions.

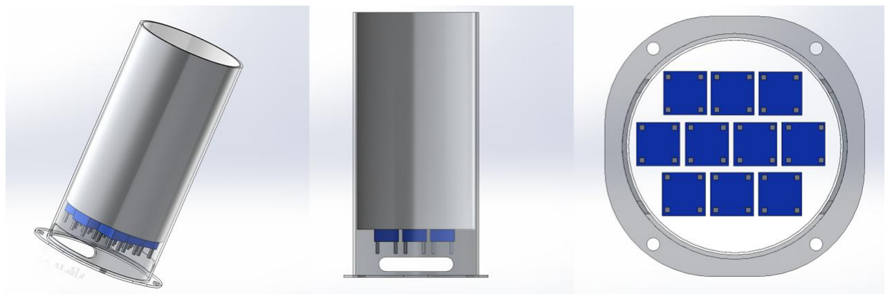
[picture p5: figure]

Figure 7 The payload sensor consisting of a NaI(Tl) crystal incapsulated in an aluminum case (transparent in the figure) and connected to the BPW34 light sensors at the bottom. Showing a 3D, Front and Bottom View.

### 6.1.4 CAD Model & Schematic

The CAD model of the Space Observatory Microsatellite was developed to provide a

comprehensive three-dimensional representation of the system architecture, including

the structural frame, payload integration, and subsystem layout. The model serves as a

critical design tool for verifying mechanical compatibility, spatial arrangement, and

overall system integration prior to fabrication.

CHAPTER 6: TECHNICAL APPROACH

The structural configuration for the EGOS-1 frame defines the primary mechanical

support of the satellite. The frame dimensions are 20 × 20 × 20 cm illustrated in

Figure 8, forming a compact cubic structure suitable for microsatellite applications. The

structure’s material is Aluminum Alloy 6061-T6 with a thickness of 1.5 mm, selected for

its high strength-to-weight ratio, mechanical durability, and suitability for space

environments.

The design includes a 10 cm diameter access hatch located on the top panel to facilitate

assembly, inspection, and integration of internal components. Additionally, dedicated

mounting interfaces are incorporated to accommodate two deployable solar panels with

dimensions of 16.5 × 10 cm each, ensuring efficient energy generation while maintaining

compact stowage during launch.

The internal architecture follows a nested stack configuration, where subsystems are

arranged in layered form to optimize space utilization and maintain a structured

integration layout. The assembly is realized using mechanical fasteners, allowing

modular construction and ease of maintenance or modification.

Complementary to the CAD model, schematic diagrams are developed to represent the

functional and electrical architecture of the microsatellite. These schematics define the

interconnection between subsystems, including power distribution networks,

communication links, payload interfaces, and onboard data handling systems.

Overall, the CAD model and schematic representation provide a complete engineering

framework for system validation, ensuring proper integration between mechanical

design and functional requirements, and supporting subsequent simulation and

implementation phases.

CHAPTER 6: TECHNICAL APPROACH

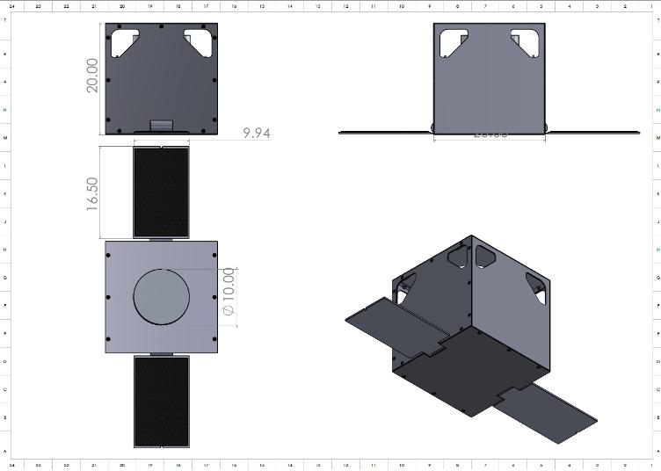
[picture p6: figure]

Figure 8 EGOS-1 frame dimensions in centimeters.

The satellite subsystems are designed to be fully interconnected and integrated with the

onboard computer, which serves as the central processing unit of the system. This central

unit is responsible for processing and analyzing incoming data, executing control

commands for satellite operation, and managing communication between the satellite

and the ground station, including both telemetry transmission and command reception.

To ensure a clear and structured system architecture, a complete electronic schematic

was developed using Proteus 9 software illustrated in Figure 9. This schematic includes

all satellite subsystems and defines the electrical and functional connections between

them, providing a detailed representation of the overall system integration.

CHAPTER 6: TECHNICAL APPROACH

Figure 9 EGOS-1 full electrical schematic on Proteus 9 software.

For the nested stack structure, the schematic was converted into a 3D PCB model to

visualize the placement of components illustrated in Figure 10, interconnections, and

embedded systems within the EGOS-1 microsatellite Earth prototype, ensuring proper

integration and spatial compatibility.

Figure 10 Exploded view of EGOS-1 illustrating all sub-systems and components in a nest stack structure with two plates in a transparent view.

CHAPTER 6: TECHNICAL APPROACH

### 6.1.5 Simulations Setup

To ensure that EGOS-1 will not fail in mission thorough different scenarios especially

during launch, deployment and operation, several simulations were conducted to ensure

the safety of this microsatellite. Static, thermal and modal simulations were conducted on

the frame.

Structural finite element analysis was performed in SolidWorks Simulation to evaluate

the mechanical integrity of the EGOS-1 frame under launch loading conditions. The

launch phase represents the most mechanically demanding event in the satellite’s

lifecycle, during which the structure must withstand quasi-static and dynamic loads

significantly exceeding normal operational levels. The simulation applies boundary

conditions representative of the loads transmitted through the launch vehicle dispenser

interface, using material properties for Aluminum Alloy 6061-T6.

### 6.1.5.1 Static Simulation

During the launching phase, the satellite undergoes high G forces that can reach up to 10

G’s. Therefore, it’s really important to ensure that the frame will not deform or fail during

launching [4],[7],[8],[9],[10],[11].

Static simulation has been conducted on SolidWorks Simulation to acquire the deflection,

maximum stress and the factor of safety of the frame, in addition to studying the hotspots

on the frame. Boundary conditions were applied as loads and fixtures, an external load of

10G was added, and the bottom plate of the frame was fixed to simulate its attachment to

the rocket. Proceeding with the simulation steps, the model was meshed with the

elements having an aspect ratio ranged between 1.020 to 11.036 as shown in Figure 11,

this big difference in the data range is due to limited computational power.

CHAPTER 6: TECHNICAL APPROACH

Figure 11 Mesh quality plot and boundary conditions showing the red arrow as the 10G external load and the green arrows as the fixture on the bottom plate in the left image. Mesh quality plot in aspect ratio in the right image.

### 6.1.5.2 Thermal Analysis

After the deployment of the satellite in orbit, it’s exposed to the sun from one side and the

other side is exposed to darkness and extreme cold weather, this variation in heat and

temperature should be simulated to ensure the stability of the temperature and if it’s the

right value for the components to operate in [12].

The average solar irradiance in LEO is 1367 W/m2 and can reach up to 1414 W/m2 in

maximum conditions. As shown in Figure 12 the first value was used as the boundary

condition for the thermal analysis of EGOS-1 on SolidWorks Flow Simulation using

conduction and radiation features and excluding fluid flow [4].

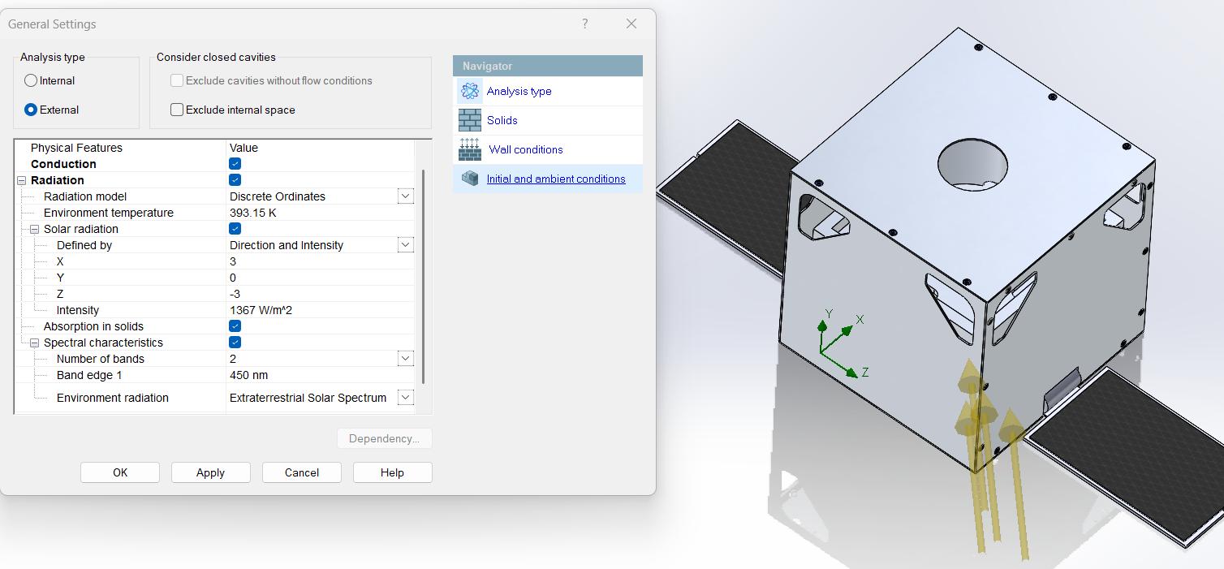
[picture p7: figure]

Figure 12 Boundary conditions of the thermal simulation of EGOS-1 showing the arrows as the sun exposure on the frame with the initial solar irradiance value.

CHAPTER 6: TECHNICAL APPROACH

### 6.1.5.3 Modal Analysis

To evaluate the dynamic behaviour of the frame, a modal analysis was conducted to

determine its natural frequencies and mode shapes. This ensures that the structure’s

natural frequencies do not coincide with the rocket excitation frequencies, thereby

preventing resonance and ensuring structural integrity during launch [9], [10], [13].

The simulation was conducted on ANSYS Student, that caused limitation in the number

of mesh elements therefore the mesh quality was really low at an element size of 5 cm.

The boundary condition was a fixed support at the bottom plate to simulate the

attachment to the rocket shown in Figure 13.

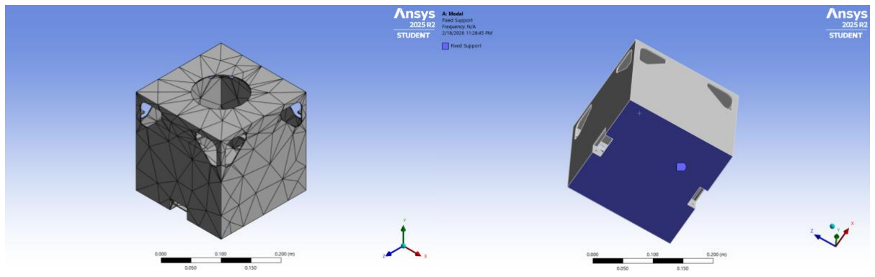
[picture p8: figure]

Figure 13 Mesh quality plot for the modal analysis (the left image), and the fixed support of the bottom plate as a boundary condition (the right image).

### 6.1.6 Simulations Results

### 6.1.6.1 Static Simulation Results

The static structural analysis was performed to evaluate the ability of the microsatellite

frame to withstand launch loads and ensure structural integrity during the most critical

phase of the mission. A 10G acceleration load was applied to simulate the mechanical

stresses experienced during launch. The results obtained from the simulation indicate

that the structure experiences a maximum deformation of 0.026 mm, which is extremely

small relative to the overall dimensions of the satellite frame (20 × 20 × 20 cm). This

minimal deformation suggests that the structural configuration of the aluminum frame is

sufficiently rigid to resist mechanical loading without experiencing significant

displacement or structural distortion.

CHAPTER 6: TECHNICAL APPROACH

The maximum equivalent stress observed in the structure was 39.371 MPa. When

compared with the yield strength of Aluminum 6061-T6 (275 MPa), the stress value

remains well below the material's allowable limit. This indicates that the material

operates far from its failure threshold under the simulated loading conditions. As a result,

the calculated factor of safety (FOS) of approximately 7 demonstrates a high structural

margin against yielding or permanent deformation. Such a safety margin is desirable in

space structures where reliability and robustness are critical due to the inability to

perform repairs once deployed in orbit.

The deformation, stress, and factor-of-safety plots presented in Figure 14 further

confirm that the stresses are distributed within acceptable limits throughout the frame.

No localized stress concentrations exceeding the material capacity were observed.

Therefore, the results indicate that the designed microsatellite frame can safely tolerate

the expected launch loads while maintaining structural integrity.

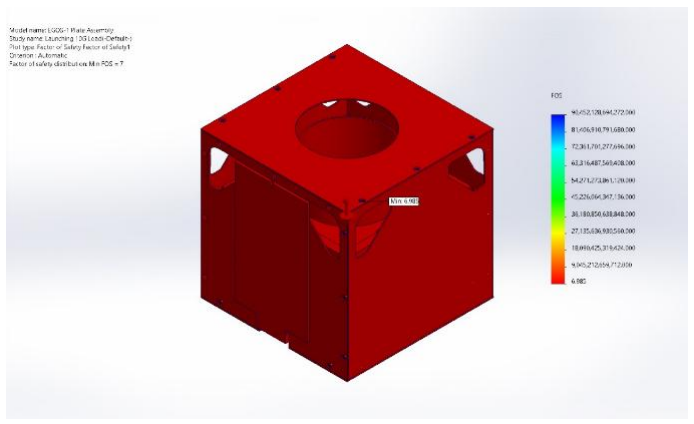
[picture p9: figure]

Figure 14 Deformation plot, Stress Plot, FOS Plot

CHAPTER 6: TECHNICAL APPROACH

### 6.1.6.2 Thermal Simulation Results

Thermal analysis was conducted to evaluate the temperature distribution across the

satellite frame under orbital environmental conditions, primarily considering exposure

to solar radiation. The simulation results indicate that the maximum temperature

reached by the structure is 411.51 K (approximately 139°C). Although this represents a

relatively high temperature compared to typical terrestrial operating conditions, it

remains within the acceptable operational limits of Aluminium 6061-T6, whose melting

point is approximately 855 K (582°C).

The temperature distribution shown in Figure 15 indicates that the thermal loading is not

uniform across the satellite structure. Regions directly exposed to solar radiation

experience higher temperatures, while shaded areas remain relatively cooler. However,

even at the peak temperature value, the structure remains well below the material’s

thermal failure limits, indicating that the frame can tolerate the expected thermal

environment in low Earth orbit.

It is important to note that the analysis focuses primarily on the structural material rather

than sensitive electronic components or payload elements. While the structural frame

can withstand these temperatures, additional thermal control strategies such as surface

coatings, insulation, or passive radiators may be required in a detailed mission design to

ensure that onboard electronics and sensors operate within their recommended

temperature ranges.

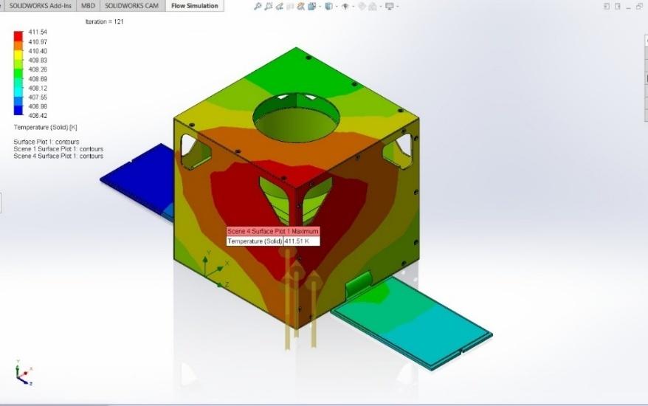
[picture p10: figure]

Figure 15 Temperature plot on the frame showing a maximum value of 411.51 K.

CHAPTER 6: TECHNICAL APPROACH

### 6.1.6.3 Modal Analysis Results

Modal analysis was performed to evaluate the dynamic behaviour of the microsatellite

structure and determine its natural frequencies and vibration modes. This analysis is

particularly important for launch conditions, where intense vibrations from the launch

vehicle can potentially excite the natural frequencies of the satellite structure and lead to

resonance.

A total of six vibration modes were analysed, and the corresponding natural frequencies

were determined, as presented in Figure 16. The associated deformation shapes for each

vibration mode are illustrated in Figure 17. These mode shapes describe the different

ways in which the satellite structure may oscillate when subjected to dynamic excitation.

The results show that the structure possesses distinct natural frequencies for each mode,

indicating predictable and stable dynamic behaviour. The deformation patterns in the

modal shapes demonstrate that the structure maintains its integrity without excessive

displacement under vibrational excitation. Importantly, the identified natural

frequencies are expected to remain sufficiently separated from the dominant frequency

ranges typically produced during launch vehicle vibrations. This separation reduces the

probability of resonance occurring during launch.

The modal deformation plots further indicate that the largest displacements occur

primarily at the outer structural elements of the frame, which is consistent with expected

behaviour in lightweight frame structures. However, these displacements remain within

acceptable limits and do not indicate structural instability.

Overall, the modal analysis confirms that the designed microsatellite frame exhibits

adequate dynamic stiffness and stability, making it suitable for surviving launch-induced

vibrations without structural failure or resonance-related amplification.

CHAPTER 6: TECHNICAL APPROACH

Figure 16 Frequency values in the 6 modes.

Figure 17 Total deformation plot in each of the 6 modes at different frequencies.

CHAPTER 6: TECHNICAL APPROACH

### 6.1.7 Discussion & Summary

The combined structural, thermal, and modal analyses provide a comprehensive

evaluation of the proposed microsatellite frame design. The static analysis confirms

strong structural robustness, with stress levels well below the material limits and

minimal deformation under simulated launch loads. The thermal analysis demonstrates

that the structure can tolerate the orbital thermal environment, although additional

thermal management may be required to protect sensitive electronic components.

Finally, the modal analysis indicates that the structure possesses adequate dynamic

stiffness and stable vibration characteristics, reducing the likelihood of resonance during

launch.

Taken together, these results suggest that the proposed microsatellite frame design

meets the fundamental structural and environmental requirements for operation in low

Earth orbit. While the analyses indicate satisfactory performance under the simulated

conditions, further refinement through detailed subsystem integration, mass

optimization, and full mission-level environmental testing would be required before final

deployment.

Figure 18 Results summary of the static, thermal and modal analysis of EGOS-1 microsatellite.

CHAPTER 6: TECHNICAL APPROACH

### 6.2 AOCS Testbed

### 6.2.1 Design Parameters

The design parameters of the AOCS testbed are derived from two sources: the design of

the microsatellite (which set the performance envelopes that the testbed must be able to

reproduce and validate), and the physical constraints of the laboratory environment,

available materials, and project budget. The parameters are organised into three groups:

Helmholtz cage magnetic field simulation, spherical air bearing mechanical platform, and

overall AOCS performance targets.

### 6.2.1.1 Helmholtz Cage Design Parameters

The primary design target for the Helmholtz cage is to generate a uniform magnetic field

of B = 100,000 nT (0.1 mT / 1 Gauss) — well above the maximum Earth's magnetic field

at LEO (approximately 0.3 to 0.6 Gauss) — to provide full coverage of the EGOS-1

operating range. The design is based on the following governing equation for the

magnetic flux density at the centre of a square Helmholtz coil pair:

B =

(2μ0NI)
πa

×

2
(1 + γ

2)√2 + γ
2

where μ₀ = 12.57 × 10⁻⁷ T·m/A (the permeability of free space), N is the number of turns

per coil, I is the current through the coil, a is the half-side-length of the square coil, and

γ = 0.5445 is the optimum coil separation-to-side-length ratio that maximises field

uniformity by eliminating second-order spatial gradient terms at the cage centre. Three

rectangular coil pairs are designed for the three orthogonal axes (XZ, XY, and YZ planes)

of the cage, each with different dimensions to accommodate the rectangular workspace,

the design parameters values are shown in Table 2.

CHAPTER 6: TECHNICAL APPROACH

Table 2 Helmholtz cage design parameters values for each axis pair

### 6.2.1.2 Spherical Air Bearing Design Parameters

The spherical air bearing is designed to support a satellite mock-up with payload

geometry of 0.30 m cube side length and payload mass of 15 kg (weight W = 15 × 9.81 =

147.2 N). It uses the aerostatic principle: compressed air at 4–6 bar gauge is fed through

a 1.0 L plenum and expelled through 13 × 1.0 mm orifices distributed over the

hemispherical bowl surface, creating a thin 20 μm air film between the sphere and bowl

that eliminates contact friction. The bearing components are 3D printed from PLA, with

key fastening via 6 ×150 mm screws to grip on the microsatellite.

Table 3 Spherical air bearing final design summary

Component | Function | Final Specification | Material
Hemisphere | Load-bearing ball | Ø300 mm, M8 boss | PLA
Bowl | Air-bearing seat | Inner R = 150 mm, depth ~150 mm | PLA
Air Film Gap | Frictionless interface | 20 μm nominal (10–50 μm
| | range)

—

Orifice Set | Air feed holes | 13 × 1.0 mm (upgradeable
| | to 1.25/1.5 mm)

PLA

Plenum | Pressure reservoir | 1.0 L volume, sealed behind
| | bowl

PLA

Supply Port | Air inlet | ¼" BSP or 8 mm push-fit | Brass/steel
Mount Interface | Satellite attachment | 6 x 150 mm threaded stud | Steel or AL6061
Axis Plane | Side Length 2a (m) | Separation 2b (m) | N (turns) | Operating Current
XZ plane | 0.75 m | 0.408375 m | 5 | 5 A (test) / 10 A (max)
XY plane | 0.714 m | 0.388773 m | 5 | 5 A (test) / 10 A (max)
YZ plane | 0.678 m | 0.369171 m | 5 | 5 A (test) / 10 A (max)

CHAPTER 6: TECHNICAL APPROACH

Air Supply System | Compressor + filter | 10 bar, 15 L tank; 5 μm
| | filter, 4500 L/min

Off-the-shelf

Pedestal / Stand | Bearing mount | 30 x 30 x 60 cm | MDF Wood

### 6.2.2 Design Environment

The AOCS testbed was designed and evaluated using an integrated hardware–software

environment combining commercial off-the-shelf (COTS) components with custom-

designed mechanical parts and in-house firmware. The environment is structured around

modularity, allowing each testbed subsystem (Helmholtz cage, air bearing, sensor suite,

control computer) to be designed, tested, and refined independently before integration.

### 6.2.2.1 Software Tools

MATLAB/Simulink (R2023a) — Primary platform for AOCS algorithm development,

attitude dynamics modelling, and Model-in-the-Loop (MIL) simulation. The Aerospace

Toolbox provides orbital mechanics, reference frame transformations (ECI, LVLH, body

frame), and the IGRF-13 geomagnetic field model for generating realistic field profiles

along the EGOS-1 orbit.

Wolfram Demonstration Project — Used for interactive Helmholtz cage magnetic field

visualisation and uniformity analysis. This tool allowed rapid parametric exploration of

coil geometry (side length, spacing, turns, current) and direct visual confirmation of the

uniform field region dimensions before fabrication.

SolidWorks (2023) with Flow Simulation add-in— Used for 3D CAD modelling of both

testbed assemblies and for the Computational Fluid Dynamics (CFD) simulation of the

spherical air bearing aerostatics.

ANSYS Fluent (2025 R1) — Used for an independent, higher-fidelity CFD validation of

the air bearing flow field under the specified boundary conditions (inlet gauge pressure

600,000 Pa, environment pressure 101,325 Pa).

CHAPTER 6: TECHNICAL APPROACH

### 6.2.3 CAD Model & Schematics

### 6.2.3.1 Helmholtz Cage CAD Model

The Helmholtz cage is modelled as three orthogonal rectangular coil-frame pairs

mounted on a common outer support structure. The outer support structure is fabricated

as an Aluminum rectangular stand, chosen for its modular assembly and non-magnetic

properties. Each coil frame is built from 18 mm Aluminium U-channel, into which 5 turns

of 4 mm² wire are wound and retained. The three coil-pair planes (XZ, XY, YZ) are

positioned and separated according to the γ = 0.5445 spacing ratio derived from the

magnetic field governing equation, yielding separations of 0.408375 m, 0.388773 m, and

0.369171 m respectively.

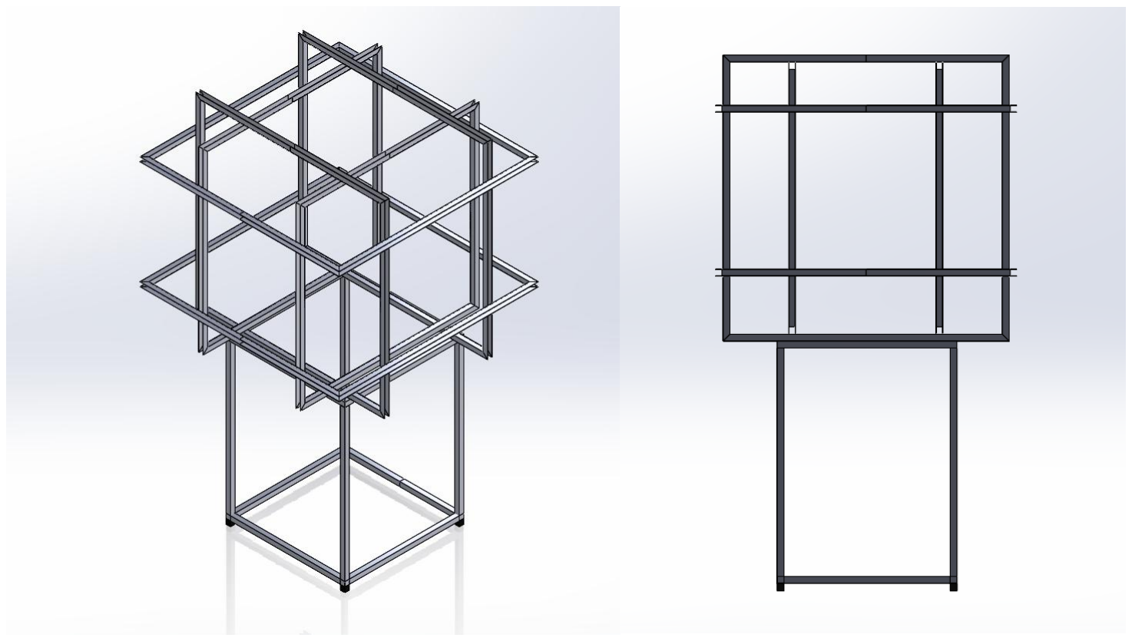
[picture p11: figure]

Figure 19 3D CAD model performed on SOLIDWORKS of the helmholtz cage structure & stand, showing the isometric view and front view.

### 6.2.3.2 Spherical Air Bearing CAD Model

The spherical air bearing CAD model captures the complete assembly: the 300 mm

diameter inner sphere, the hemispherical bowl (inner radius R = 150.000 mm, depth

~150 mm, with 13 × 1.0 mm orifices) with 4 x 6 mm holes to mount the specimen on the

hemisphere using a grip mechanism, the inlet fitting is a ¼" BSP.

The complete assembly is mounted on an MDF wood pedestal (30 cm diameter) at a

height that centres the sphere and mounted satellite within the Helmholtz cage working

CHAPTER 6: TECHNICAL APPROACH

volume. The total height of the air bearing assembly on the pedestal is designed to align

the satellite CoM with the geometric centre of the Helmholtz cage.

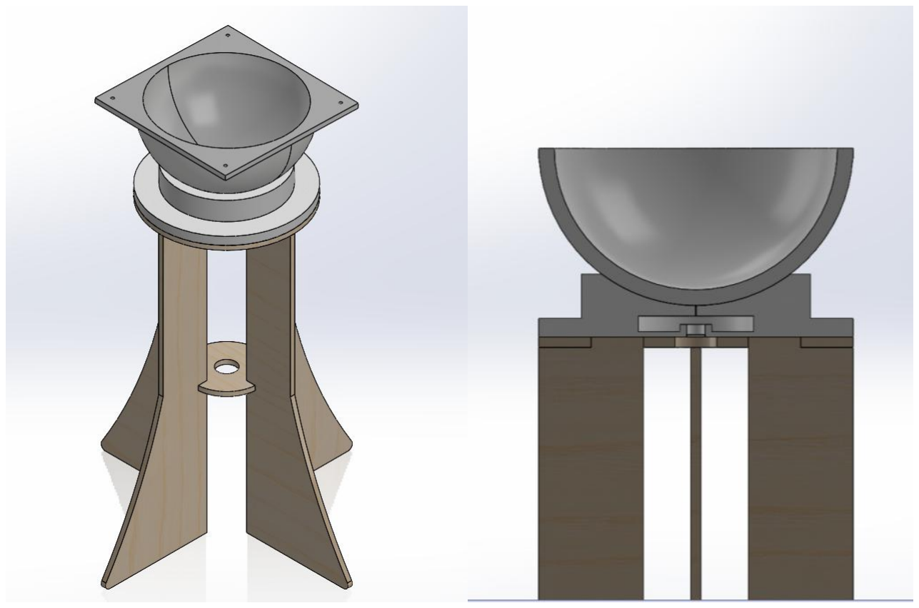
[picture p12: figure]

Figure 20 Spherical air bearing 3D CAD model on SOLIDWWORKS, showing the isometric view and the sectional front view to illustrate the air chamber and the central orifice.

### 6.2.3.3 Complete AOCS Testbed 3D CAD Model

Integerating all subsystems together, in addition to the EGOS-1 microsatellite we will

come to this 3D CAD model illustrated in Figure 21.

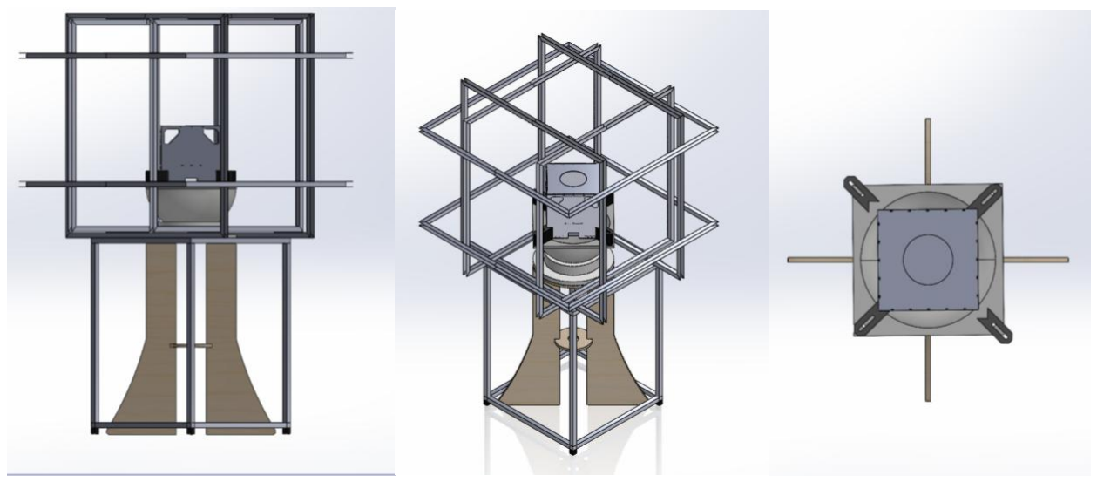
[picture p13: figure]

Figure 21 Full system 3D CAD model showing 2 various views, and the top view to illustrate the gripping mechanism on the microsatellite, showing 2 diagonal tight grips and 2 loose grips.

CHAPTER 6: TECHNICAL APPROACH

### 6.2.4 Simulations Setup

Two independent simulation analyses were performed to validate the testbed design: (1)

magnetic field uniformity simulation of the Helmholtz cage using the Wolfram

Demonstration tool, and (2) CFD simulation of the air bearing using SolidWorks Flow

Simulation and ANSYS Fluent 2025 R1 in parallel.

### 6.2.4.1 Helmholtz Cage Magnetic Simulation Setup

The Wolfram Demonstration tool computed the axial magnetic flux density profile

B_z(0,0,0) and the field distribution in the axial (z) and transverse (y) directions for each

of the three cage axis planes. Input parameters: coil side lengths 0.75 m / 0.714 m / 0.678

m, separations per γ = 0.5445, N = 5 turns, I = 5 A.

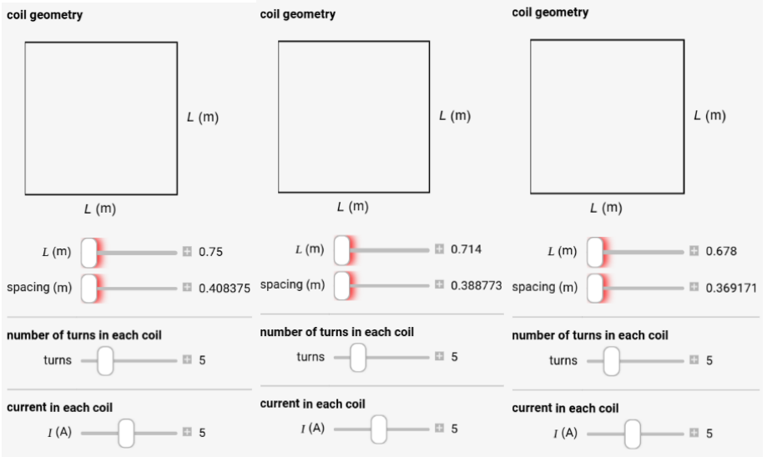
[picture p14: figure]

Figure 22 The input parameters for the Helmholtz cage simulation to solve for the magnetic flux density and the homogenious distance.

CHAPTER 6: TECHNICAL APPROACH

### 6.2.4.2 Air Bearing CFD Setup

In SolidWorks Flow Simulation, the bearing geometry was imported from the CAD model.

Boundary conditions: total pressure inlet = 600,000 Pa (6 bar gauge), environment

pressure outlet = 101,325 Pa. Simulation goals: lifting force on sphere (GG Force Y),

average total pressure, shear stresses, mass flow rate, and outlet velocity. Convergence

at 85 iterations.

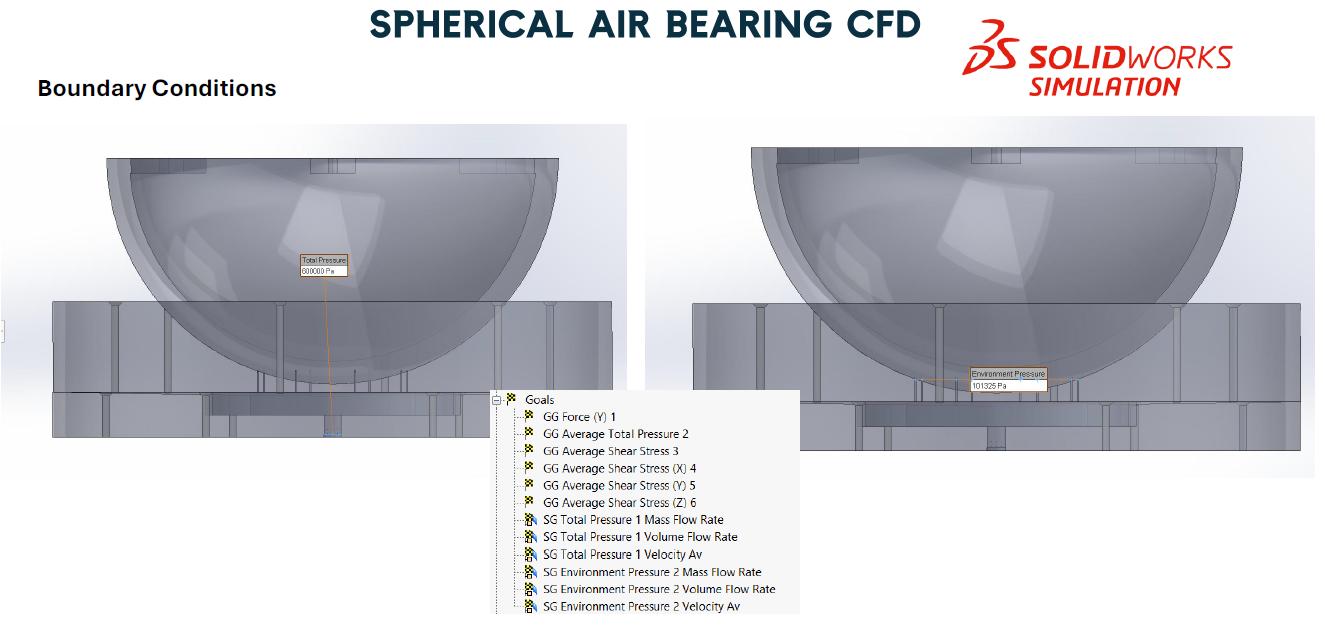
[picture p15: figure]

Figure 23 SOLIDWORKS Flow Simulation boundary conditions for the spherical air bearing: inlet total pressure 600,000 Pa (left) and environment pressure outlet 101,325 Pa (right). Simulation goals are listed in the centre panel.

CHAPTER 6: TECHNICAL APPROACH

In ANSYS Fluent 2025 R1, the same geometry was independently modelled with a

pressure-inlet boundary (gauge total pressure = 600,000 Pa) and atmospheric outlet.

Solver: pressure-based, steady-state, k–ε turbulence model.

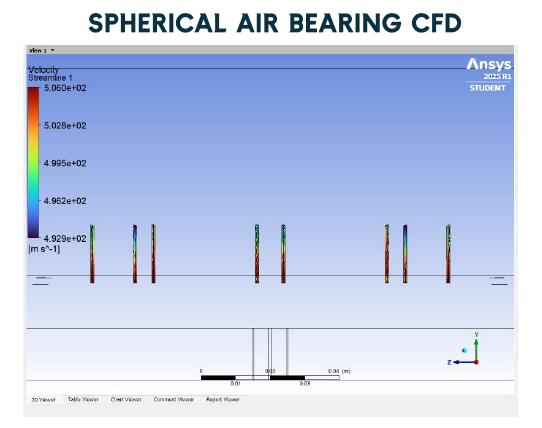
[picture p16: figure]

Figure 24 ANSYS Fluent 2025 R1 setup for the spherical air bearing CFD simulation: bowl geometry with pressure inlet at 600,000 Pa gauge (normal to boundary), and velocity streamline initialisation showing the eight orifice inlet jets.

CHAPTER 6: TECHNICAL APPROACH

### 6.2.5 Simulations Results

### 6.2.5.1 Helmholtz Cage Magnetic Field Results

The Wolfram simulation produced axial field profiles for all three cage planes at I = 5 A.

All three planes generate fields within the Earth's LEO magnetic field range (0.3–0.6

Gauss), confirming the design is correct for AOCS sensor testing at the specified operating

current. The Earth's magnetic field range of 0.3–0.6 Gauss is achieved at 5 A, while the

maximum designed field of 1 Gauss is achieved at 10 A.

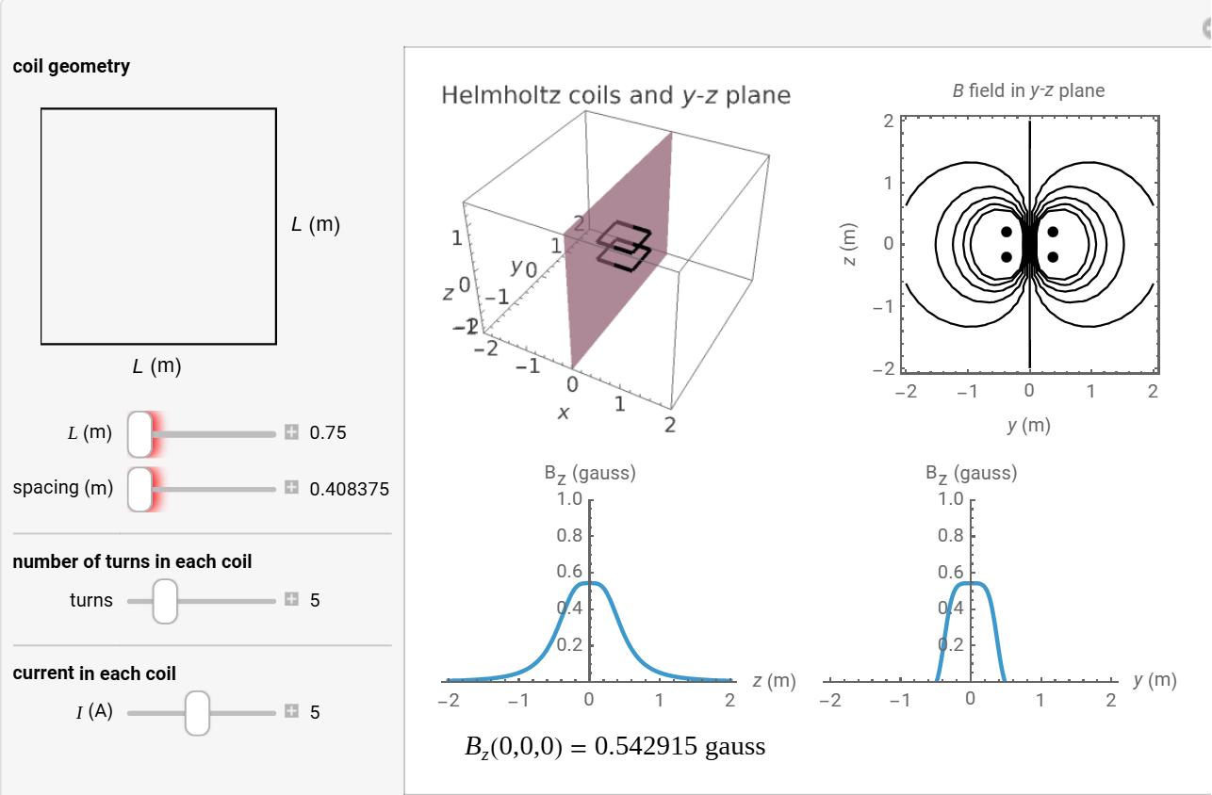
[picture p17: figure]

Figure 25 Wolfram Demonstration magnetic simulation for the XZ plane (2a = 0.75 m, N = 5, I = 5 A): B_z vs z (left) and B_z vs y (right) profiles, confirming B_z(0,0,0) = 0.542915 Gauss and a broad uniform-field plateau.

Table 4 Helmholtz cage magnetic simulation results: central field and uniform region for each axis plane at I = 5 A.

Plane | B_z(0,0,0) [Gauss] | B_z(0,0,0) [nT] | Uniform Field Region
XZ | 0.542915 | 54,2915 | ± ~0.45 m from centre
XY | 0.571606 | 57,1606 | ± ~0.45 m from centre
YZ | 0.600569 | 60,0569 | ± ~0.45 m from centre

CHAPTER 6: TECHNICAL APPROACH

### 6.2.5.2 Spherical Air Bearing CFD Results

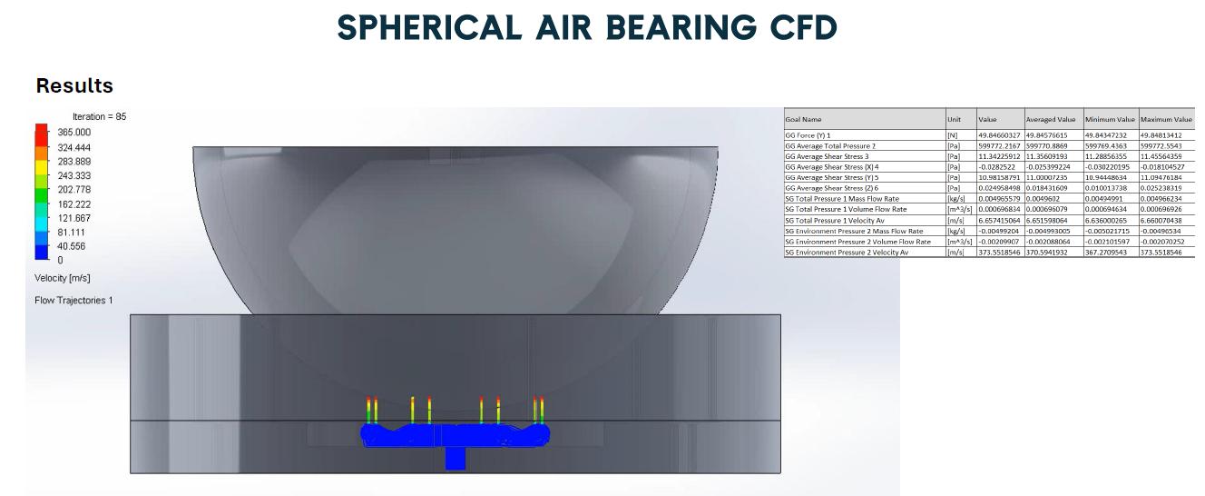
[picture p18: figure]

Figure 26 SolidWorks Flow Simulation results at iteration 85: velocity flow trajectories (left, scale 0– 365 m/s) showing symmetric air film formation between the orifice jets and the sphere surface. The results table (right) shows GG Force Y = 49.845 N (averaged)

Table 5 SolidWorks Flow Simulation results for the spherical air bearing (6 bar inlet, 13 × 1.0 mm orifices, 85 iterations).

Goal / Output | Value (Averaged) | Unit
GG Force Y (lifting force on sphere) | 49.845 | N
GG Average Total Pressure (bowl surface) | 599,770.89 | Pa
GG Average Shear Stress (total) | 11.356 | Pa
SG Total Pressure — Average Velocity | 6.658 | m/s
SG Total Pressure — Mass Flow Rate | 0.00490 | kg/s
SG Environment Pressure — Avg Outlet Velocity | 370.594 | m/s

CHAPTER 6: TECHNICAL APPROACH

Table 6 ANSYS Fluent 2025 R1 CFD results for the spherical air bearing. Both tools agree on the lifting force to within < 0.01%.

Result | Value | Unit
Net upward thrust (lifting force) | 49.85 | N
Outlet maximum velocity (orifice jet) | 506 | m/s

### 6.2.6 Discussion

### 6.2.6.1 Helmholtz Cage

The simulations confirm that the three-axis rectangular Helmholtz cage with N = 5 turns

and γ = 0.5445 spacing generates the Earth's magnetic field range (0.3–0.6 Gauss) at I =

5 A — well within standard laboratory DC power supply ratings. The maximum field of 1

Gauss at 10 A provides a 3× margin above the Earth's field upper bound, enabling sensor

saturation and over-range calibration tests. The uniform field region of 0.45 m radius

from the cage centre comfortably encloses the EGOS-1 mock-up (maximum dimension 20

cm on the air bearing), providing 12.5 cm clearance margin on each side. The slightly

different per-axis field strengths (0.542915, 0.571606, and 0.600569 Gauss at 5 A) result

from the rectangular geometry and are compensated by adjusting each axis current

independently, which is standard Helmholtz cage practice.

### 6.2.6.2 Spherical Air Bearing

Both SolidWorks and ANSYS Fluent agree on a lifting force of 49.85 N against the required

147.2 N. This shortfall is fully explained by choked-flow physics: at a supply-to-ambient

pressure ratio of 600,000 / 101,325 ≈ 5.9 (above the critical ratio of ~1.89 for air), the

orifice mass flow is at its maximum for 13 × 1.0 mm holes. The outlet jet velocities of 370–

506 m/s confirm choked flow. The strong agreement between the two independent CFD

tools validates the simulation methodology.

CHAPTER 7: DELIVERABLES & IMPLEMENTATION

# 7. Deliverables & Implementation

### 7.1 Space Observatory Microsatellite

For the implementation of the EGOS-1 microsatellite, the hardware components,

including the microsatellite frame, electronic systems, and circuit assemblies, were

designed, modelled, and fabricated according to the previously specified dimensions and

schematics. However, due to fabrication limitations associated with the payload

subsystem, the scintillating crystal could not be manufactured. Consequently, the payload

implementation was excluded from the final prototype development.

Additionally, an issue was encountered with the dimensions of the supplied solar panels.

Due to stock unavailability, the supplier provided panels with dimensions slightly larger

than those originally specified in the order. As a result, the solar panels were

incompatible with the designed mounting base and could not be properly aligned or

integrated into the microsatellite structure. Consequently, the solar panels were excluded

from the final implementation.

### 7.1.1 Hardware Components

The hardware components are categorized into two main subsystems: the electronic

components and the structural frame.

### 7.1.1.1 Electronic Components

The electronics in any microsatellite are divied to subsystems depending on there

functionality, the subsystems are:

- Electrical Power Subsystem (EPS)
- On-Board Computer (OBC)
- Attitude & Orbit Control System (AOCS)
- Communication System (COMMS)

The following Table 7 illustrates the final installed components and there modules.

CHAPTER 7: DELIVERABLES & IMPLEMENTATION

Table 7 Final installed electrical components for the EGOS-1 trial model.

Electrical Power Subsystem (EPS)

Component | Module | Function

3S2P 12 V Li-Ion Battery

18650 12V 3S-

2P+BMS 6000mAh

Power Source

DC Power Distributor 4-Channel Module

Power Distributor

Module for 5–48V

Systems With Per-

Channel 10A

Outputs

Multiple Power Outputs

2x Adjustable DC-DC Step-Down

Converter

XL4015 Adjustable

DC-DC Step-Down

Module with

Display 5A 75W

Controls voltage output

to match the input for

other devices.

Onboard Computer (OBC) + Communciation System (COMMS)

Component | Module | Function
ESP32 Dual-Core MCU (240 MHz) | ESP32 DevBoard

Data management and

controlling other

systems, and telemetry

acquisition.

Attitude & Orbit Control System (AOCS)

Component | Module | Function

Brushless DC Motor — Reaction Wheel

A2212 BLDC

Motor

Constant correction of

the satellites attitude.

Electronic Speed Controller (ESC) | 40A ESC

Drives the motor with

precise current.

CHAPTER 7: DELIVERABLES & IMPLEMENTATION

Custom Magnetorquers ×2

240-turn coils of

0.4 mm enamelled

copper wire

Interacts with Earth's

field B to produce

torque τ = m × B about

the pitch and roll axes.

Dual H-Bridge Driver | L298N

Controls current

magnitude and

direction in each

magnetorquer coil for

pitch and roll control.

IMU | MPU-6050

Six-axis MEMS sensor

(gyroscope +

accelerometer)

providing three-axis

angular rate feedback
via I²C for the real-time

control loop.

Magnetometer | HMC5883L

Three-axis magnetic

field sensor (up to 160
Hz, I²C) for attitude

determination and

magnetorquer feedback

control.

Listing all of the components and there function, and studying there data sheet will lead

to the step of making the final schematic for the mictrosatellite model. The purchased

components and the final implemented schematic is shown in Figure 27.

CHAPTER 7: DELIVERABLES & IMPLEMENTATION

Figure 27 The final purchased components (right image) & The final schematic (left image).

### 7.1.1.2 Structural Frame Fabrication

The microsatellite frame consists of a hollow cubic structure with overall dimensions of

20 × 20 × 20 cm and includes a circular hatch with a diameter of 10 cm located on the top

surface, as previously illustrated in

Figure 8. The structure is composed of six individual plates: two front plates, two side

plates, one top plate, and one bottom plate. Each plate has a thickness of 1.5 mm, and

when assembled, they form the final cubic configuration.

The selected manufacturing method for the frame components was CNC laser cutting.

Initially, Aluminum T6061 was considered as the primary construction material due to

its lightweight properties and high thermal conductivity, which make it suitable for heat

dissipation applications in space systems. However, due to material availability and

manufacturing convenience, Stainless Steel 304 (SS304) was utilized instead. Although

SS304 has a significantly higher density, approximately three times heavier than

Aluminum T6061, it was considered acceptable for the fabrication of the Earth-based trial

model.

CHAPTER 7: DELIVERABLES & IMPLEMENTATION

Prior to the CNC laser cutting process, final modifications were implemented on the

design model using the Sheet Metal features in SOLIDWORKS. A tab-and-slot mechanism

was incorporated into the design to facilitate the assembly and secure installation of the

mounting strips onto the plates. Additionally, internal support shelves were integrated

into the structure to accommodate and support the nested stack configuration as shown

in Figure 28.

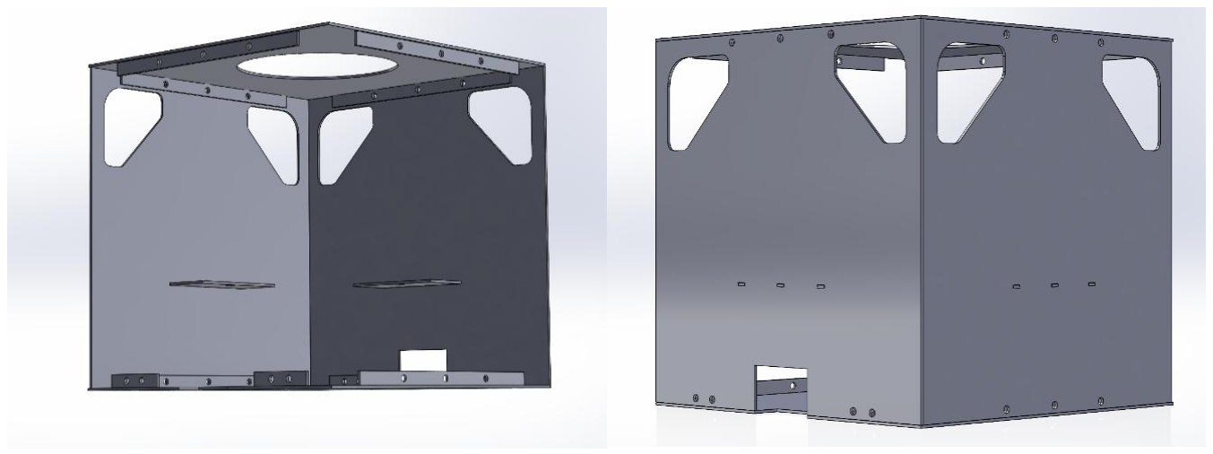
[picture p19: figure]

Figure 28 Plate assembly of the frame using the tab-and-slot feature to install the mounting strips that will hold the plates together, also showing the mounting shelf.

The CNC laser cutting manufacturing process was successfully completed, and the frame

was fabricated and assembled with high dimensional accuracy in accordance with the

finalized design specifications as shown in Figure 29.

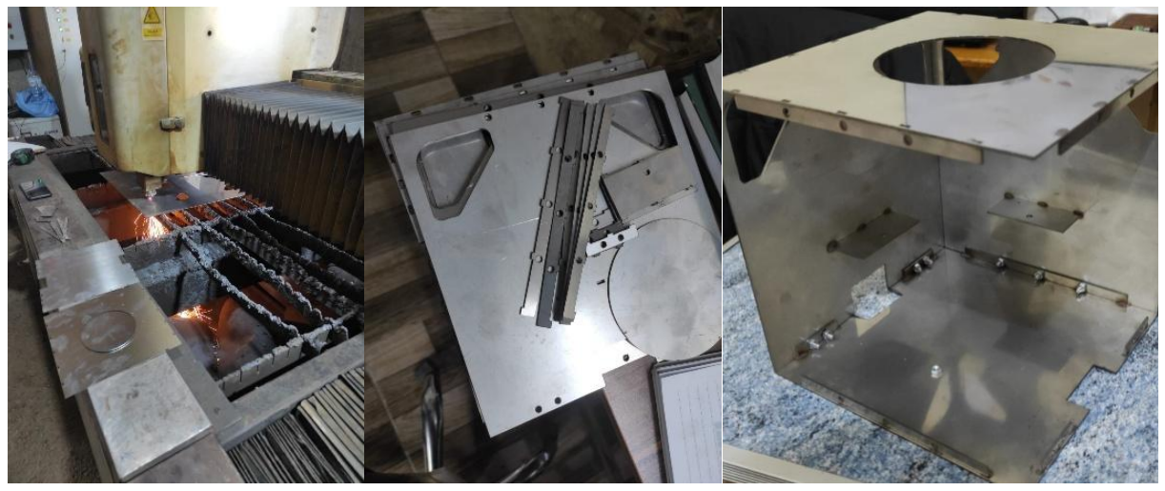
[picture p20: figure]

Figure 29 The CNC laser cutting process of the structural frame plates (left image), the plates and mounting strips before assembly (middle image), the plates during assembly using 4mm button head bolts with nuts (right image.)

CHAPTER 7: DELIVERABLES & IMPLEMENTATION

### 7.1.2 Control & Software

The software system operates on the ESP32 microcontroller, which is responsible for

managing the Attitude and Orbit Control System (AOCS) and communication processes.

The firmware was developed using the Arduino IDE in the C++ programming language.

The primary objective of the software is to execute the control algorithm (shown in

Figure 31) responsible for acquiring state data from the inertial measurement and

magnetic field sensors, namely the MPU6050 and HMC5883L modules. The collected

sensor data is processed to determine the satellite’s attitude and calculate the required

corrective actions. These corrections are then applied through the actuators, including

the reaction wheel and magnetorquers, to stabilize and control the satellite orientation.

Furthermore, the system telemetry and operational data are visualized through a real-

time dashboard implemented using embedded HTML code integrated within the

firmware.

### 7.1.2.1 Attitude Determination

The ESP32 continuously acquires angular velocity and acceleration data from the MPU-

6050 sensor, in addition to three-axis magnetic field measurements from the HMC5883L magnetometer, through the I²C communication protocol at fixed sampling intervals. A

complementary filter algorithm is implemented to fuse the gyroscope integration data

with magnetometer-based tilt correction, enabling real-time estimation of the satellite’s

roll, pitch, and yaw orientation angles with improved stability and reduced drift.

### 7.1.2.2 Attitude Control — PD Controller

A Proportional-Derivative (PD) controller was implemented to compute the attitude

error, defined as the difference between the measured orientation and the commanded

reference angle, and to generate the corresponding actuator control signals. For yaw-axis

stabilization, the controller outputs a PWM speed command to the reaction wheel

electronic speed controller (ESC), while current commands are supplied to the L298N

magnetorquer driver for pitch and roll attitude correction.

CHAPTER 7: DELIVERABLES & IMPLEMENTATION

The controller gains were optimized using the Particle Swarm Optimization (PSO)

artificial intelligence technique on the AOCS experimental testbed to achieve improved

system stability, response time, and control performance.

### 7.1.2.3 Telemetry Dashboard

The ESP32 hosts a lightweight HTTP server through its integrated Wi-Fi access point,

enabling wireless communication and monitoring capabilities. A browser-based

telemetry dashboard was developed to display real-time system parameters, including

attitude angles, angular velocities, magnetometer measurements, and actuator operating

states.

Through the dashboard interface shown in Figure 30, operators are able to transmit

attitude control commands directly to the system for testing and operational purposes.

Additionally, all acquired telemetry and control data are logged into the onboard flash

memory to facilitate data storage, analysis, and post-processing evaluation.

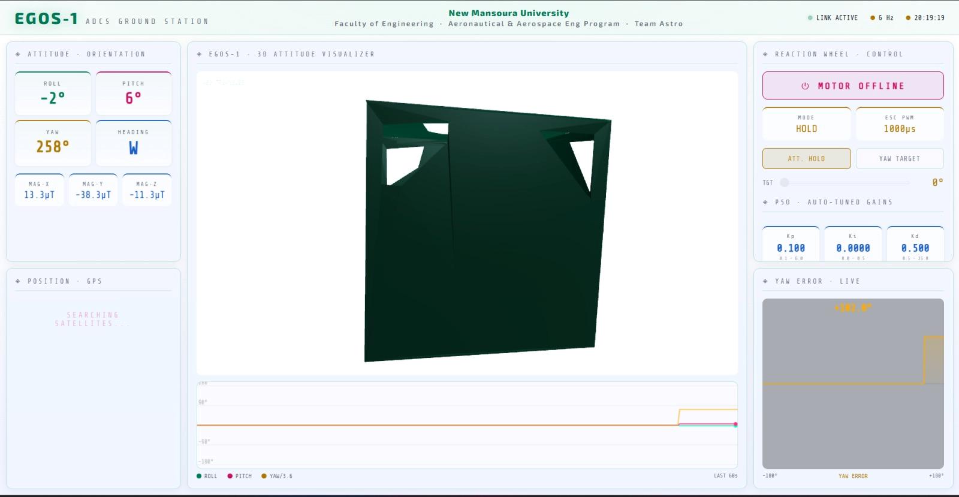
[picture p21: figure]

Figure 30 Telemetry dashboard for EGOS-1 microsatellite.

CHAPTER 7: DELIVERABLES & IMPLEMENTATION

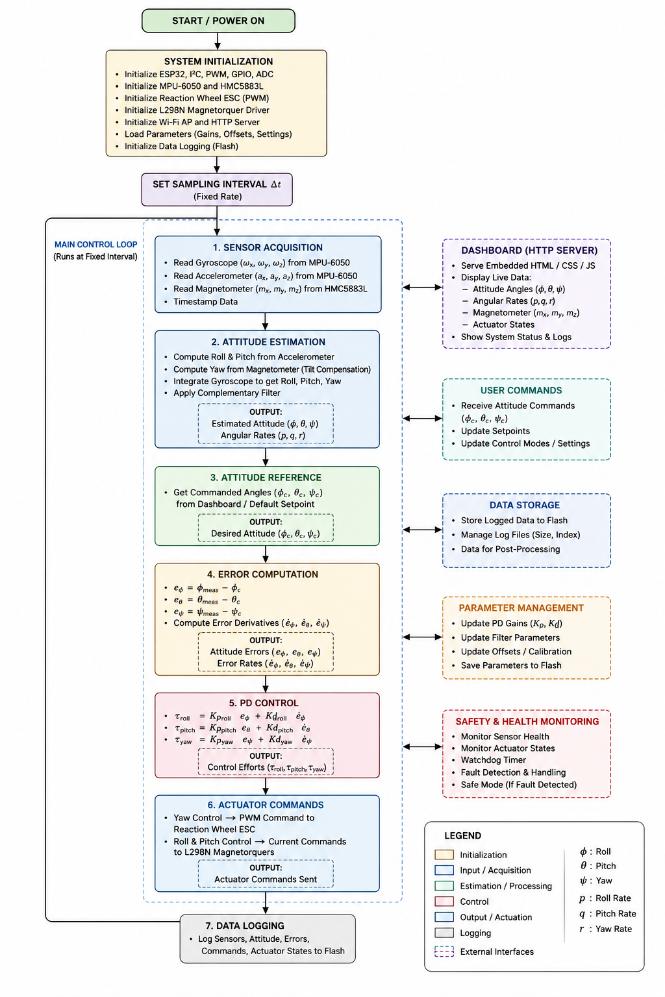
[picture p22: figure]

Figure 31 The control algorithim for the microsatellite's software.

CHAPTER 7: DELIVERABLES & IMPLEMENTATION

### 7.2 AOCS Testbed

### 7.2.1 Hardware Components

The AOCS testbed hardware is composed of two primary mechanical subsystems: the

Helmholtz cage and the spherical air-bearing assembly. These subsystems are supported

by auxiliary components, including a variable power supply, pneumatic support

equipment. All hardware components were selected and integrated to satisfy the

magnetic field generation and rotational freedom requirements outlined in Section 6.2.

### 7.2.1.1 Helmholtz Cage Fabrication

Shown in Table 8 are the hardware components used to make and assemble the

Helmholtz cage, showing the components in Figure 32.

Table 8 Hardware components for the Helmholtz cage.

Component | Specifications | Function

U-Channel Aluminum Profile

8 x 18mm x 75 cm

8 x 18mm x 71.4 cm

8 x 18mm x 67.8 cm

Support the coils

winding and build the

structure of the cage.

Winding Wire

4.0 mm² Stranded Wire –

Elsewedy Electric H07V-R

PVC Insulated

The coils copper wire

generating the

magnetic field.

Zip Ties | 6 mm x 30 cm

Fasteners to hold the

cage together

Stand | 50 x 50 x 60 cm

Supporting the cage on

the floor and centering

it with the spherical air

bearing.

CHAPTER 7: DELIVERABLES & IMPLEMENTATION

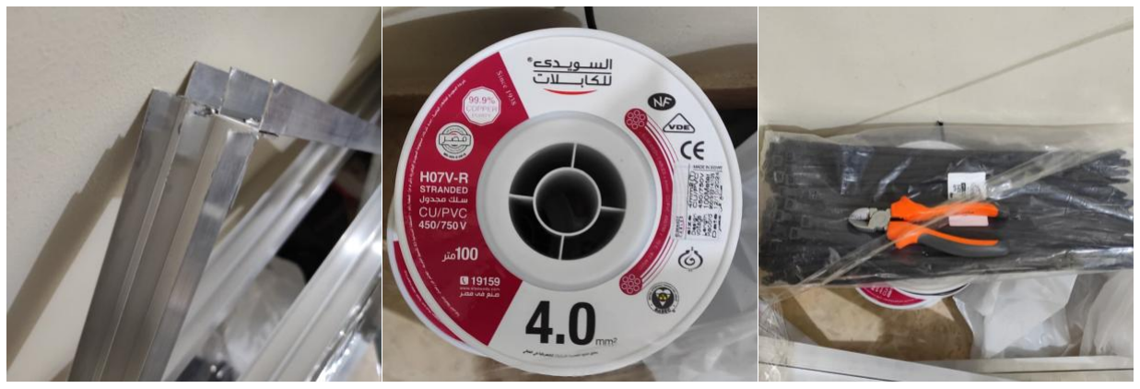
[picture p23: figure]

Figure 32 The U-channel aluminum profile (left image), The 4mm2 stranded insulated wire (middle image), The zip ties used as fasteners (right image).

### 7.2.1.2 Spherical Air Bearing Fabrication

The fabrication of the spherical air-bearing system involved modelling the final assembly

components using SOLIDWORKS, followed by manufacturing the designed parts through

3D printing using PLA material. The fabricated components were assembled and tested

to ensure proper functionality and rotational performance of the spherical air-bearing

mechanism. Additionally, a mounting table stand fabricated from MDF wood was

constructed to provide structural support and stable installation for the spherical air-

bearing assembly during testing and experimental operation. The fabrication and

assembly phase are illustrated in Figure 33.

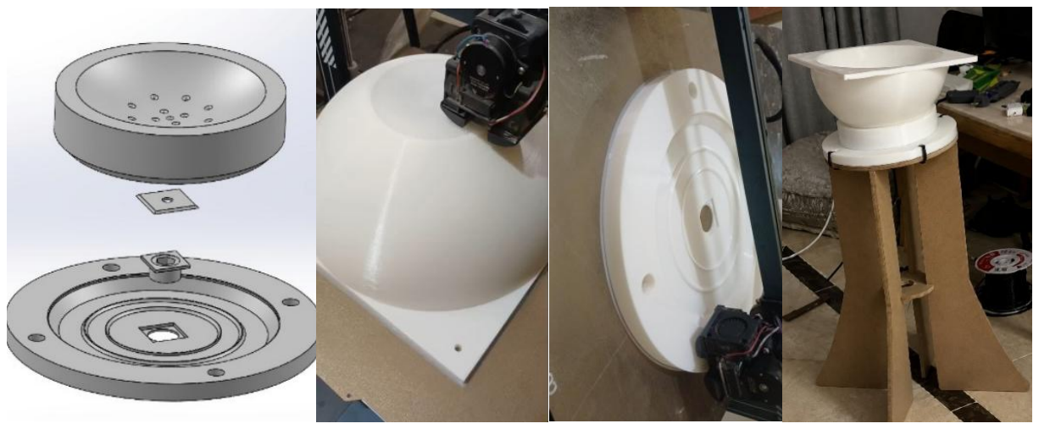
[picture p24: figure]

Figure 33 Final modelling of the assembly on SOLIDWORKS (left image), The 3D printing process of the parts (middle images), Final implemented assembly with stand (right image).

CHAPTER 7: DELIVERABLES & IMPLEMENTATION

### 7.2.2 Control

The testbed control framework is operated through an adjustable power supply

connected to the Helmholtz cage to regulate the generated magnetic field intensity, while

an air compressor system with a controllable valve is utilized to adjust the air pressure

supplied to the spherical air-bearing assembly. This configuration enables precise control

of both the magnetic simulation environment and the rotational freedom conditions

during experimental testing.

### 7.2.2.1 Helmholtz Cage — Current Control

The required current values for each Helmholtz cage axis are determined based on the

simulation results presented in Section 6.2.5, which provide the expected Earth magnetic

field vector components (B_x, B_y, B_z). The operator manually adjusts the corresponding

power supply currents for each coil axis to reproduce the desired magnetic field

conditions. This approach enables the satellite’s magnetometers and magnetorquers to

be evaluated and tested under a wide range of simulated orbital magnetic environments

representative of real Earth-orbit conditions.

### 7.2.2.2 Spherical Air Bearing — Pressure Control

Pressurized air supplied by the air compressor enters the spherical air-bearing inlet and

flows through the designed orifices, generating a thin air film that enables the

hemispherical structure to float with minimal friction. The supplied pressure can be

adjusted using the compressor regulator to achieve stable operational conditions.

Based on the simulations presented in Section 6.2.5, the recommended operating

pressure range was determined to be between 2 and 4 bar. Exceeding this pressure limit

may generate an unstable airflow condition and localized shockwave effects, which can

disrupt the air film stability and lead to malfunction of the spherical air-bearing system.

In the following figures the operation diagram of the AOCS testbed is illustrated in Figure

34 addition to the final fabrication of the full project.

CHAPTER 7: DELIVERABLES & IMPLEMENTATION

Figure 34 Testbed operation diagram

Figure 35 Full testbed + specimen project operating in a lab at New Mansoura University.

CHAPTER 8: POSSIBLE STAKEHOLDERS

# 8. Possible Stakeholders

The EGOS-1 micro-satellite and AOCS Testbed project addresses a well-defined gap in

Egypt's space engineering infrastructure. By combining a scientifically capable satellite

platform with a domestically fabricated, low-cost test facility, the project creates tangible

value for a broad and diverse set of stakeholders across government, academia, and

industry as illustrated in Table 9.

Potential stakeholders were identified based on alignment with two primary project

outputs: (1) the EGOS-1 micro-satellite as a scientific and educational platform, and (2)

the AOCS Testbed as a replicable laboratory infrastructure product.

Table 9 Stakeholders list of the project.

Category | Stakeholder | Type | Role & Interest

Schools

Ministry of Education

& Technical

Education

Government

Interested in adding space

and satellite engineering

topics to STEM education

programs.

Schools

Egyptian Japanese

Schools (EJS)

Educational

Potential users of educational

satellite kits and practical

engineering activities.

Schools | STEM Egypt Schools | Educational

Interested in hands-on

satellite experiments and

STEM-based space projects.

Universities

Ministry of Higher

Education &

Scientific Research

Government

Supports university research,

STEM development, and

local space technology

projects.

Universities

Academy of Scientific

Research and

Technology (ASRT)

Research Funding

Possible funding partner for

EGOS-1 development and

testing activities.

CHAPTER 8: POSSIBLE STAKEHOLDERS

Universities

The British University

in Egypt (BUE)

Private University

Potential research partner for

AOCS systems and satellite

engineering projects.

Universities

Zewail City of

Science and

Technology

Research University

Interested in astrophysics,

satellite systems, and

advanced space research.

Research

Centers &

Organizations

Egyptian Space

Agency (EgSA)

Space Agency

Main national space

authority supporting local

satellite design,

manufacturing, and testing.

Research

Centers &

Organizations

National Research

Centre (NRC)

Research Institution

Interested in materials,

engineering research, and

satellite structural testing.

Research

Centers &

Organizations

National Authority for

Remote Sensing and

Space Sciences

(NARSS)

Space Science

Interested in satellite data

and low-cost local satellite

platforms.

Research

Centers &

Organizations

National Research

Institute of

Astronomy and

Geophysics (NRIAG)

Scientific Research

Interested in gamma-ray and

astrophysics data from the

EGOS-1 mission.

Research

Centers &

Organizations

Space Science Center

— Cairo University

(SSC/CU)

Research Center

Potential collaborator in

satellite research and AOCS

testbed applications.

CHAPTER 8: POSSIBLE STAKEHOLDERS
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

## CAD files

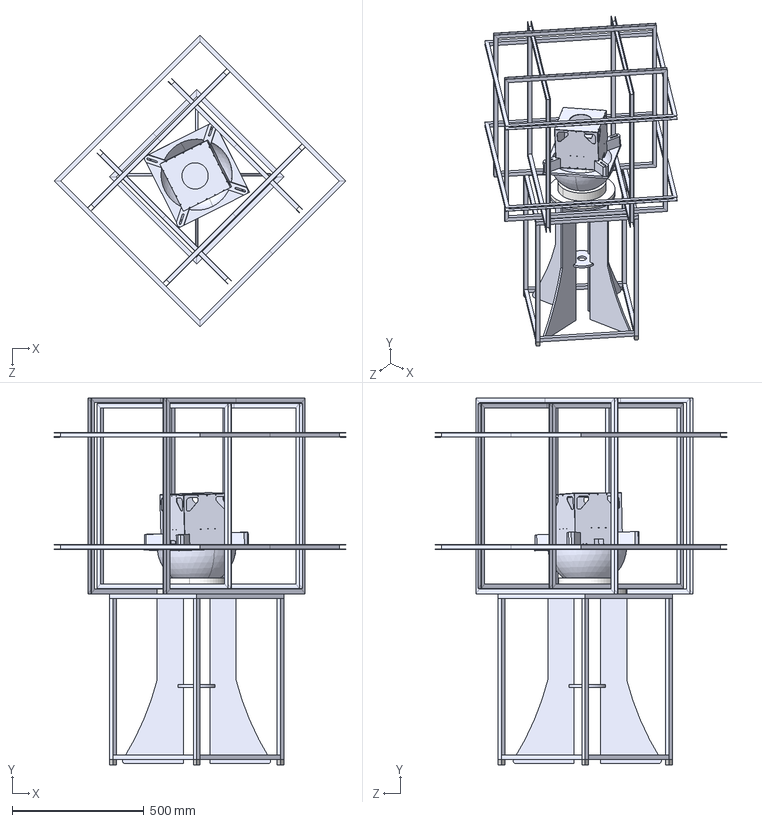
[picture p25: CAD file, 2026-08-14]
Full AOCS CAD Model.STEP
1108.7 x 1394.0 x 1108.7 mm
Hemisphere-0
EGOS-1 Plate Sheet Metal
Mount x 4
SAB Stand
new spherical air bearing
18x18x1mm 75cm U x 2
18x18x1mm 71cm U x 2
18x18x1mm 67cm U x 2
H Stand

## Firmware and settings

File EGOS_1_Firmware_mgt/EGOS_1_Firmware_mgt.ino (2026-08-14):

// NOTE: stl_model.h must be in the same sketch folder
#include "stl_model.h"

/*
 * ============================================================
 *  EGOS-1 CubeSat ADCS Ground Station Firmware
 *  Enhanced: WebGL STL Viewer | Orientation Graphs | PSO Auto-Tuned PID
 *            Magnetorquer Control (B-dot detumble + PD pointing)
 *  MCU: ESP32 | Framework: Arduino
 * ============================================================
 */

#include <Wire.h>
#include <QMC5883LCompass.h>
#include <Adafruit_MPU6050.h>
#include <Adafruit_Sensor.h>
#include <MadgwickAHRS.h>
#include <WiFi.h>
#include <WebServer.h>
#include <TinyGPSPlus.h>
#include <ESP32Servo.h>
#include <ESPmDNS.h>

// ── Sensor / Filter objects ─────────────────────────────────
QMC5883LCompass compass;
Adafruit_MPU6050 mpu;
Madgwick filter;
TinyGPSPlus gps;
WebServer server(80);
Servo reactionWheel;

// ── WiFi ────────────────────────────────────────────────────
const char* ssid     = "HAMMOUDA";     // <-- Enter your router's SSID
const char* password = "0500961615"; // <-- Enter your router's Password

// ── Telemetry ───────────────────────────────────────────────
int finalRoll = 0, finalPitch = 0, finalYaw = 0;
String cardinalDir = "N";
double gpsLat = 0.0, gpsLng = 0.0, gpsAlt = 0.0;
int gpsSats = 0;
float magX_uT = 0.0, magY_uT = 0.0, magZ_uT = 0.0;
unsigned long lastTime = 0;

// ━━━━━━━━━━━━━━━━━━━━━━━━━━━━━━━━━━━━━━━━━━━━━━━━━━━━━━━━━━
//  MAGNETORQUER SYSTEM
//  2 torque rods: ROLL axis (X) and PITCH axis (Y)
//  Driver: L298N H-bridge, one rod per channel
//
//  Power supply:
//    L298N motor pins (VS) → 3 V external supply
//    L298N logic pin (VSS) → ESP32 5V pin
//    Common GND
//
//  Torque rod specs (from physical dimensions):
//    Core  : Nickel-iron, ∅6 mm × 60 mm  (µ_eff ≈ 50)
//    Wire  : 0.4 mm copper, N = 250 turns
//    R     ≈ 0.70 Ω   L ≈ 1.85 mH   τ ≈ 2.65 ms
//    Dipole moment ≈ 0.354 A·m² per Ampere
//    Max safe current: 1.0 A  (L298N continuous limit @ 3 V)
//    ⚠ Do NOT exceed 1.0 A – R is only 0.7 Ω so 3 V can push 4 A
//       The PWM duty is capped to enforce this limit.
//
//  L298N wiring:
//    Roll  rod → OUT1/OUT2  (IN1=G25, IN2=G26, ENA=G33)
//    Pitch rod → OUT3/OUT4  (IN3=G27, IN4=G13, ENB=G32)
//
//  Control strategy:
//    Phase 1 – B-dot detumble : active while |ω| > BDOT_THRESH (rad/s)
//    Phase 2 – PD pointing    : active when satellite is calm
// ━━━━━━━━━━━━━━━━━━━━━━━━━━━━━━━━━━━━━━━━━━━━━━━━━━━━━━━━━━

// ── L298N pin assignments ────────────────────────────────────
// Roll channel (OUT1/OUT2)
constexpr int MTQ_ROLL_IN1 = 25;
constexpr int MTQ_ROLL_IN2 = 26;
constexpr int MTQ_ROLL_ENA = 33;   // PWM-capable pin

// Pitch channel (OUT3/OUT4)
constexpr int MTQ_PITCH_IN3 = 27;
constexpr int MTQ_PITCH_IN4 = 13;  // G13 — safe, non-boot-sensitive
constexpr int MTQ_PITCH_ENB = 32;  // PWM-capable pin

// ── LEDC PWM channels (ESP32 Arduino core v3.x) ─────────────
// In v3.x the pin IS the channel — no ledcSetup/ledcAttachPin needed.
// Just call ledcAttach(pin, freq, resolution) then ledcWrite(pin, duty).
constexpr int LEDC_FREQ  = 5000;   // 5 kHz – above audible, well below L/R corner
constexpr int LEDC_RES   = 8;      // 8-bit → 0–255 duty

// ── Torque rod physical constants (250 turns, 3 V supply) ────
constexpr float MTQ_DIPOLE_PER_AMP = 0.354f;   // A·m² / A
constexpr float MTQ_ROD_R          = 0.70f;    // Ω  – low! beware overcurrent
constexpr float MTQ_SUPPLY_V       = 3.0f;     // V
// Hard current cap — L298N continuous limit is 2 A; we use 1 A for safety
constexpr float MTQ_MAX_CURRENT    = 1.0f;     // A
// Duty at which 1 A flows: I = (duty/255) * V_supply / R  → duty = I*R/V * 255
constexpr int   MTQ_MAX_DUTY = (int)(MTQ_MAX_CURRENT * MTQ_ROD_R / MTQ_SUPPLY_V * 255); // ≈ 59

// ── B-dot controller parameters ─────────────────────────────
constexpr float BDOT_GAIN   = 5.0f;    // k in m = -k * Ḃ
constexpr float BDOT_THRESH = 0.05f;   // rad/s  – switch to PD below this

// ── PD pointing parameters (roll & pitch) ───────────────────
constexpr float MTQ_KP = 0.8f;   // proportional gain (A / degree)
constexpr float MTQ_KD = 2.5f;   // derivative gain   (A / (degree/s))
constexpr float MTQ_ANGLE_DEADBAND = 1.5f;  // degrees – no action inside this

// ── State ───────────────────────────────────────────────────
bool   mtqEnabled     = false;
int    mtqRollDuty    = 0;    // –255 to +255 (sign = direction)
int    mtqPitchDuty   = 0;
float  prevBx = 0.0f, prevBy = 0.0f;   // for B-dot differentiation
float  prevRollRate  = 0.0f;
float  prevPitchRate = 0.0f;
String mtqPhase = "IDLE";     // "BDOT", "PD", "IDLE"

// ── Helper: drive one L298N channel ─────────────────────────
// duty: –255 (full reverse) to +255 (full forward), 0 = off
void driveChannel(int in1, int in2, int enPin, int duty) {
  duty = constrain(duty, -255, 255);
  if (duty == 0) {
    digitalWrite(in1, LOW);
    digitalWrite(in2, LOW);
    ledcWrite(enPin, 0);
  } else if (duty > 0) {
    digitalWrite(in1, HIGH);
    digitalWrite(in2, LOW);
    ledcWrite(enPin, (uint8_t)duty);
  } else {
    digitalWrite(in1, LOW);
    digitalWrite(in2, HIGH);
    ledcWrite(enPin, (uint8_t)(-duty));
  }
}

// ── Main magnetorquer update – call every loop iteration ─────
void updateMagnetorquers(float roll_deg, float pitch_deg,
                         float gx, float gy,          // body rates rad/s
                         float bx, float by, float bz,// body frame B-field (µT)
                         float dt) {
  if (!mtqEnabled || dt <= 0.0f) {
    driveChannel(MTQ_ROLL_IN1,  MTQ_ROLL_IN2,  MTQ_ROLL_ENA,  0);
    driveChannel(MTQ_PITCH_IN3, MTQ_PITCH_IN4, MTQ_PITCH_ENB, 0);
    mtqRollDuty  = 0;
    mtqPitchDuty = 0;
    mtqPhase = "IDLE";
    return;
  }

  // ── Measure tumble rate magnitude ──────────────────────────
  float omega = sqrtf(gx*gx + gy*gy);

  float rollDuty  = 0.0f;
  float pitchDuty = 0.0f;

  if (omega > BDOT_THRESH) {
    // ════════════════════════════════════════════════
    //  PHASE 1 – B-dot detumble
    //  Torque command: m = -k * dB/dt
    //  L298N duty ∝ required dipole moment
    // ════════════════════════════════════════════════
    mtqPhase = "BDOT";

    float dBx = (bx - prevBx) / dt;   // µT/s
    float dBy = (by - prevBy) / dt;

    // Desired dipole (A·m²) for each axis
    float mx_cmd = -BDOT_GAIN * dBx;
    float my_cmd = -BDOT_GAIN * dBy;

    // Convert dipole → current → duty (0–255)
    float ix = mx_cmd / MTQ_DIPOLE_PER_AMP;
    float iy = my_cmd / MTQ_DIPOLE_PER_AMP;

    ix = constrain(ix, -MTQ_MAX_CURRENT, MTQ_MAX_CURRENT);
    iy = constrain(iy, -MTQ_MAX_CURRENT, MTQ_MAX_CURRENT);

    rollDuty  = (ix / MTQ_MAX_CURRENT) * MTQ_MAX_DUTY;
    pitchDuty = (iy / MTQ_MAX_CURRENT) * MTQ_MAX_DUTY;

  } else {
    // ════════════════════════════════════════════════
    //  PHASE 2 – PD pointing (roll & pitch to zero)
    // ════════════════════════════════════════════════
    mtqPhase = "PD";

    float rollRate  = (roll_deg  - prevRollRate)  / dt;  // deg/s approx
    float pitchRate = (pitch_deg - prevPitchRate) / dt;

    // Roll axis torque rod (X axis)
    float rollErr = roll_deg;   // target = 0°
    if (fabsf(rollErr) > MTQ_ANGLE_DEADBAND) {
      float ix = MTQ_KP * rollErr + MTQ_KD * rollRate;
      ix = constrain(ix, -MTQ_MAX_CURRENT, MTQ_MAX_CURRENT);
      rollDuty = (ix / MTQ_MAX_CURRENT) * MTQ_MAX_DUTY;
    }

    // Pitch axis torque rod (Y axis)
    float pitchErr = pitch_deg;  // target = 0°
    if (fabsf(pitchErr) > MTQ_ANGLE_DEADBAND) {
      float iy = MTQ_KP * pitchErr + MTQ_KD * pitchRate;
      iy = constrain(iy, -MTQ_MAX_CURRENT, MTQ_MAX_CURRENT);
      pitchDuty = (iy / MTQ_MAX_CURRENT) * MTQ_MAX_DUTY;
    }

    prevRollRate  = roll_deg;
    prevPitchRate = pitch_deg;
  }

  // ── Apply to hardware ─────────────────────────────────────
  mtqRollDuty  = constrain((int)rollDuty,  -MTQ_MAX_DUTY, MTQ_MAX_DUTY);
  mtqPitchDuty = constrain((int)pitchDuty, -MTQ_MAX_DUTY, MTQ_MAX_DUTY);

  driveChannel(MTQ_ROLL_IN1,  MTQ_ROLL_IN2,  MTQ_ROLL_ENA,  mtqRollDuty);
  driveChannel(MTQ_PITCH_IN3, MTQ_PITCH_IN4, MTQ_PITCH_ENB, mtqPitchDuty);

  // ── Save previous B for next B-dot differentiation ───────
  prevBx = bx;
  prevBy = by;
}

// ── Motor / PID ─────────────────────────────────────────────
const int motorPin  = 18;
const int IDLE_PWM    = 1500;   // ESC mid-point: motor spins at idle speed
const int STANDBY_PWM = 1000;   // guaranteed below every ESC's run threshold
const int MAX_DELTA   = 400;    // max ±µs authority around idle (1100–1900)
bool motorEnabled   = false;
int  controlMode    = 0;       // 0 = Hold, 1 = Target
int  targetYaw      = 0;
int  currentPWM     = STANDBY_PWM;

float Kp = 0.0, Ki = 0.0, Kd = 0.0;   // set by PSO at startup
float integralError = 0.0, previousError = 0.0;

// ━━━━━━━━━━━━━━━━━━━━━━━━━━━━━━━━━━━━━━━━━━━━━━━━━━━━━━━━━━
//  PARTICLE SWARM OPTIMISATION  –  offline PID auto-tuner
//  Runs once during setup() before the main loop starts.
//
//  Plant model: reaction wheel = double integrator.
//    wheel speed  ω  integrates torque input u
//    yaw angle    θ  integrates the reaction torque (-ω * gain)
//  This correctly captures the integrating nature of the plant
//  and naturally produces low Kp, near-zero Ki, dominant Kd.
//
//  Search bounds are sized for a small CubeSat reaction wheel
//  (A2212-class BLDC, ±400 µs authority, 50 Hz control loop).
//
//  Gain hard-limits (also enforced in the live PID loop):
//    Kp : 0.1  – 8.0
//    Ki : 0.0  – 0.5
//    Kd : 0.5  – 25.0
// ━━━━━━━━━━━━━━━━━━━━━━━━━━━━━━━━━━━━━━━━━━━━━━━━━━━━━━━━━━
namespace PSO {
  // Hard gain limits – enforced both here and in the live loop
  constexpr float KP_MIN = 0.1f,  KP_MAX =  8.0f;
  constexpr float KI_MIN = 0.0f,  KI_MAX =  0.5f;
  constexpr float KD_MIN = 0.5f,  KD_MAX = 25.0f;

  constexpr int   N_PARTICLES = 12;
  constexpr int   N_ITER      = 80;
  constexpr float W  = 0.55f;   // inertia weight
  constexpr float C1 = 1.5f;    // cognitive coeff
  constexpr float C2 = 1.5f;    // social coeff

  // Double-integrator reaction-wheel plant:
  //   dω/dt = u / J_wheel          (wheel spin-up from torque)
  //   dθ/dt = -ω * (J_wheel/J_sat) (yaw from wheel momentum)
  // Normalised so u is a fraction of MAX_DELTA, output θ in degrees.
  float cost(float kp, float ki, float kd) {
    const float dt      = 0.02f;   // 50 Hz
    const int   SIM     = 300;     // 6 s of simulation
    const float Jratio  = 0.08f;   // J_wheel / J_sat (typical small CubeSat)
    float theta = 0.0f, omega = 0.0f;
    float integ = 0.0f, prev_e = 1.0f;
    float itae  = 0.0f;
    for (int t = 0; t < SIM; t++) {
      float e    = 1.0f - theta;          // setpoint = 1 normalised degree
      integ     += e * dt;
      integ      = constrain(integ, -50.0f, 50.0f);
      float deriv = (e - prev_e) / dt;
      float u    = kp * e + ki * integ + kd * deriv;
      u          = constrain(u, -1.0f, 1.0f);   // normalised ±1 authority
      omega     += u / Jratio * dt;
      omega      = constrain(omega, -500.0f, 500.0f);
      theta     -= omega * Jratio * dt;
      // Penalty: overshoot beyond 20% is heavily punished
      float penalty = (fabsf(theta) > 1.2f) ? 10.0f * fabsf(fabsf(theta) - 1.2f) : 0.0f;
      itae      += (float)(t + 1) * dt * fabsf(e) + penalty;
      prev_e     = e;
    }
    return itae;
  }

  // Lightweight LCG random – avoids rand() seeding issues on ESP32
  uint32_t seed = 0xDEADBEEFu;
  float randf() {
    seed = seed * 1664525u + 1013904223u;
    return (float)(seed >> 8) / (float)(1u << 24);
  }

  struct Particle {
    float pos[3], vel[3], best[3];
    float bestCost;
  };

  void run(float &outKp, float &outKi, float &outKd) {
    float lo[3] = { KP_MIN, KI_MIN, KD_MIN };
    float hi[3] = { KP_MAX, KI_MAX, KD_MAX };

    Particle swarm[N_PARTICLES];
    float gBest[3];
    float gBestCost = 1e30f;

    // Initialise particles
    for (int i = 0; i < N_PARTICLES; i++) {
      for (int d = 0; d < 3; d++) {
        swarm[i].pos[d]  = lo[d] + randf() * (hi[d] - lo[d]);
        swarm[i].vel[d]  = (randf() - 0.5f) * (hi[d] - lo[d]) * 0.1f;
        swarm[i].best[d] = swarm[i].pos[d];
      }
      swarm[i].bestCost = cost(swarm[i].pos[0], swarm[i].pos[1], swarm[i].pos[2]);
      if (swarm[i].bestCost < gBestCost) {
        gBestCost = swarm[i].bestCost;
        for (int d = 0; d < 3; d++) gBest[d] = swarm[i].pos[d];
      }
      yield();   // feed watchdog
    }

    // Main PSO loop
    for (int iter = 0; iter < N_ITER; iter++) {
      for (int i = 0; i < N_PARTICLES; i++) {
        for (int d = 0; d < 3; d++) {
          float r1 = randf(), r2 = randf();
          swarm[i].vel[d] = W  * swarm[i].vel[d]
                          + C1 * r1 * (swarm[i].best[d] - swarm[i].pos[d])
                          + C2 * r2 * (gBest[d]         - swarm[i].pos[d]);
          swarm[i].pos[d] += swarm[i].vel[d];
          swarm[i].pos[d]  = constrain(swarm[i].pos[d], lo[d], hi[d]);
        }
        float c = cost(swarm[i].pos[0], swarm[i].pos[1], swarm[i].pos[2]);
        if (c < swarm[i].bestCost) {
          swarm[i].bestCost = c;
          for (int d = 0; d < 3; d++) swarm[i].best[d] = swarm[i].pos[d];
          if (c < gBestCost) {
            gBestCost = c;
            for (int d = 0; d < 3; d++) gBest[d] = swarm[i].pos[d];
          }
        }
      }
      yield();   // feed watchdog every iteration
    }

    outKp = gBest[0];
    outKi = gBest[1];
    outKd = gBest[2];
    Serial.printf("[PSO] Done — Kp=%.3f Ki=%.4f Kd=%.3f  ITAE=%.4f\n",
                  outKp, outKi, outKd, gBestCost);
  }
} // namespace PSO
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
void loop() {
  server.handleClient();

  // ── GPS decode ───────────────────────────────────────────
  while (Serial2.available() > 0) {
    if (gps.encode(Serial2.read())) {
      if (gps.location.isValid()) { gpsLat = gps.location.lat(); gpsLng = gps.location.lng(); }
      if (gps.altitude.isValid())  gpsAlt  = gps.altitude.meters();
      if (gps.satellites.isValid()) gpsSats = gps.satellites.value();
    }
  }

  // ── Attitude math ────────────────────────────────────────
  unsigned long currentTime = micros();
  float dt = (currentTime - lastTime) / 1e6f;
  if (dt <= 0.0f) { delay(1); return; }
  lastTime = currentTime;

  filter.begin(1.0f / dt);

  sensors_event_t a, g, temp;
  mpu.getEvent(&a, &g, &temp);
  compass.read();

  float mx = compass.getY();
  float my = -1.0f * compass.getX();
  float mz = compass.getZ();

  magX_uT = mx / 30.0f;
  magY_uT = my / 30.0f;
  magZ_uT = mz / 30.0f;

  filter.update(
    g.gyro.x * RAD_TO_DEG, g.gyro.y * RAD_TO_DEG, g.gyro.z * RAD_TO_DEG,
    a.acceleration.x, a.acceleration.y, a.acceleration.z,
    mx, my, mz
  );

  float roll  = filter.getRoll();
  float pitch = filter.getPitch();
  float yaw   = filter.getYaw() + 4.5f;  // local magnetic declination offset
  if (yaw <   0.0f) yaw += 360.0f;
  if (yaw >= 360.0f) yaw -= 360.0f;

  finalRoll  = (int)roundf(roll);
  finalPitch = (int)roundf(pitch);
  finalYaw   = (int)roundf(yaw);

  const char* dirs[] = {"N","NE","E","SE","S","SW","W","NW"};
  cardinalDir = dirs[(int)((yaw + 22.5f) / 45.0f) % 8];

  // ── PID / Reaction Wheel ─────────────────────────────────
  if (!motorEnabled) {
    currentPWM    = STANDBY_PWM;  // motor stopped, ESC stays armed
    integralError = 0.0f;
    previousError = 0.0f;
  } else {
    float error = (float)(targetYaw - finalYaw);
    // Shortest angular path
    while (error >  180.0f) error -= 360.0f;
    while (error < -180.0f) error += 360.0f;

    integralError += error * dt;
    // Anti-windup clamp
    integralError = constrain(integralError, -100.0f, 100.0f);

    float derivative = (dt > 0.0f) ? (error - previousError) / dt : 0.0f;

    // Hard-clamp gains to PSO limits before use (safety guardrail)
    float kp = constrain(Kp, PSO::KP_MIN, PSO::KP_MAX);
    float ki = constrain(Ki, PSO::KI_MIN, PSO::KI_MAX);
    float kd = constrain(Kd, PSO::KD_MIN, PSO::KD_MAX);

    float pidOut = (kp * error) + (ki * integralError) + (kd * derivative);

    // PID output is an offset from idle – clamp to ±MAX_DELTA
    int delta   = constrain((int)pidOut, -MAX_DELTA, MAX_DELTA);
    currentPWM  = IDLE_PWM + delta;
    previousError = error;
  }

  reactionWheel.writeMicroseconds(currentPWM);

  // ── Magnetorquers ─────────────────────────────────────────
  updateMagnetorquers(
    roll, pitch,
    g.gyro.x, g.gyro.y,        // body rates (rad/s from MPU6050)
    magX_uT, magY_uT, magZ_uT, // ambient B-field from QMC5883L (µT)
    dt
  );

  delay(15);  // ~50 Hz sensor loop
}
